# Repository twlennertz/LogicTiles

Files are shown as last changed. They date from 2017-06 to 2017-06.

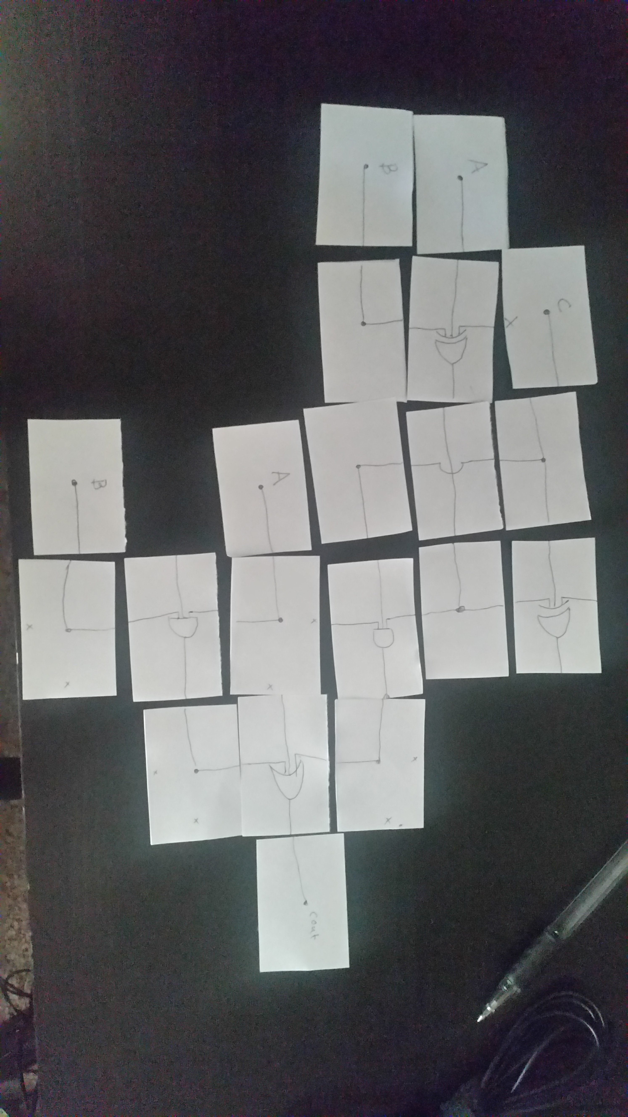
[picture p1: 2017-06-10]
non-code_project_files/Design Diagrams/rectangles.jpg

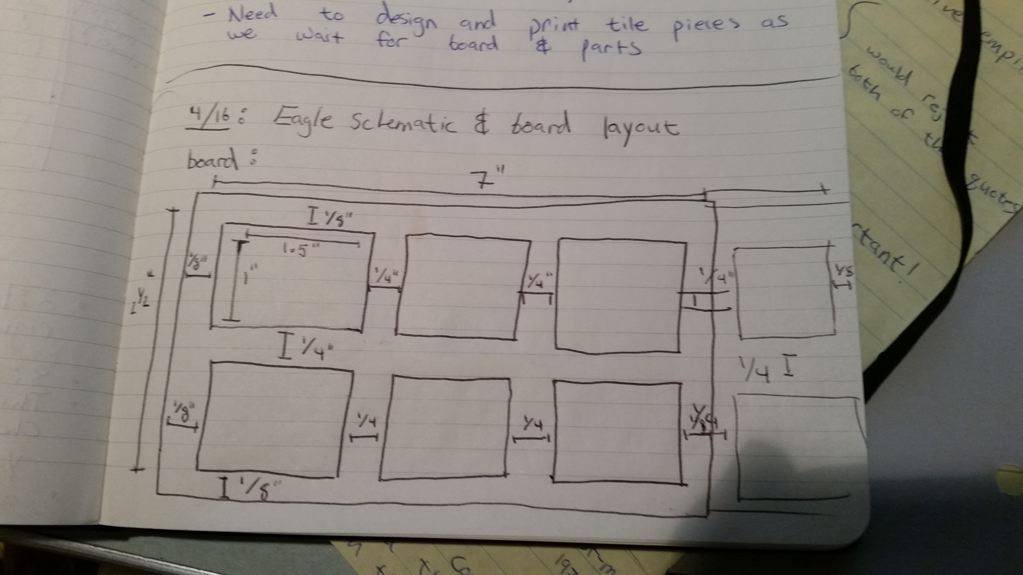
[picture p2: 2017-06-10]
non-code_project_files/Design Diagrams/Board_Dimensions.jpg

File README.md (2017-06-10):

<h2>Digital Logic Tile Board Project</h2>

Spring 2017 Senior Project

Cal Poly CPE Department

Authors: Tristan Lennertz & Andrew Wheeler

Implemented for the MSP430 Family

<h3>Please see Project Report for detailed information on this project</h3>

main: The main state machine loop, inits, terminal interface and commands, and ISRs

tiles: Pertains to addressing, selecting, reading, and determining the types of the tiles on the board

graph: Involves the creation and traversal of the graph that underlies and represents the digital circuit

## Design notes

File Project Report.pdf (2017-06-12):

# Logic Tiles

### A Senior Project

### presented to

### the Faculty of the Computer Engineering Department

### California Polytechnic State University, San Luis Obispo

### In Partial Fulfillment

### of the Requirements for the Degree

### Bachelor of Science, Computer Engineering

by

### Tristan Lennertz & Andrew Wheeler

### June 2017

©Tristan Lennertz, Andrew Wheeler

T

a

# ble

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
rvie

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
cisio

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
Tile

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
Tile

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
Tile

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
cisio

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
al Alg

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
Tile

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
r Im

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
# Introduction

## Overview

This project was originally conceived by Professor Andrew Danowitz as he considered the restructuring of the introductory digital design course at Cal Poly. As it stands now, students apply their knowledge of boolean algebra and combinatorial logic through the programming of a Field Programmable Gate Array (FPGA) using a Hardware Descriptive Language (HDL). While this is the industry standard for designing large, complex digital circuits, and is an fundamental skill to learn, there is a lack of actual circuit building in the process that can cause a disconnect from theory to application for students who have little-to-no experience with digital logic. Our project attempts to bridge that gap by providing a physical device with which students can manually develop their own digital circuits, forming them on a board as they place representative tiles onto it. They can then view in real time how their circuits are affected by certain inputs or restructuring of connections. This would be a useful supplement in the course that helps to emphasize the descriptive, and not procedural, nature of HDLs.

## Background / Design Decisions

To formulate the design of our project, we researched methods employed to teach programming to children and young adults. The closest thing we found to our project was a children's toy called Cubetto; Cubetto is a small robot that is controlled by a board that children place passive tiles onto in order to issue instructions. The concept of this board was very similar to the board we had envisioned, and so we did more research into Cubetto’s inception. This type of learning, called tangible learning, eventually led us to a thesis by Timothy McNerney of MIT in 1983, in which he proposed physical building blocks that were used to construct simple programs (his work would later lead to the development of the Lego Mindstorm series of educational toys) [2].

His application of the idea, however, was through the process of stacking many active units that would communicate via I

2C, which did not meet our desire to use passive tiles like Cubetto. McNerney’s work, lead us to an article by Andrew C Smith of the Meraka Institute who utilized passive elements on a board to manipulate a toy Robot [4]. From his research we discovered

that the passive elements contained a series of magnets embedded into them that would trigger specific reed switches on the board itself, giving each block a unique code that could be deciphered by a connected microcontroller.

We decided to use Smith’s technique but wanted to reduce the cost of the parts used. While Smith’s design was simple and used the presence and absence of a magnetic field to determine the encoding, required up to 9 magnets to be placed on each piece. Furthermore, each place for a block on the board needed 9 reed switches, so Smith’s prototype used a large and costly play field. Conversely, our project needed a multitude of different tile types and many small spaces on the board to place them. From this we decided to use Hall Effect sensors instead of reed switches, as a hall effect sensor can detect a magnetic presence in the same way as a reed switch, but it can also differentiate the magnetic strength and polarity [6]. This allowed us to use fewer magnets on our passive tiles and would instead vary the strength and polarity of the magnet.

We briefly considered RFID instead of magnets but decided to use magnets for a several reasons. First, though RFID tags have gone down considerably in cost in recent years, they would still be more expensive to implement. The least expensive RFID reader we found would cost about $10 and we would need at least one per tile space on the board. Compared to the hall-effect sensors (which cost <$1 each) the RFID reader’s cost per tile area would be close to (or even than) three times the cost of the number of hall-effect sensors we would need for the same tile area. Another advantage of magnets over RFID is that we can deduce orientation of our tile from magnets. RFID is unable to detect this, as it can only detect proximity, but we could gather the orientation from the polarity of the magnet.

## Project Goals

End Users

As stated in our overview, the main end users of our project are Electrical and Computer Engineering students. While they are assumed to have a certain degree of technical experience, we should expect that a majority of them have little or no skills related to digital logic and design. They should, however, have the knowledge to manipulate a simple terminal interface and light debugging skills.

Digital design professors would also use our system. Their main interaction with our system would be debugging student circuits. It is likely they would have prior training with the system and would be more knowledgeable in its operation than students.

Design Requirements

Seeing as our end users are students with little experience in digital design, we need to make sure that our device is robust and easy to use. Adding a new tile or gate to the circuit should be as easy as placing it on a corresponding place on the board and our system should quickly (within a second) detect that a new tile has been place and what the type the tile is. Students can then interact with the circuit using a companion terminal interface that is connected to the circuit board, allowing them to manipulate source values and read the signal value at various places on the circuit. Furthermore, we would like our system to be able to report to the student when they have incorrectly constructed the circuit and give them a hint as to where the problem lies. We do not want to directly tell them where the issue is as this is an education tool and the act of debugging the circuit is a part of the educational experience. We also decided that, because of the availability of physical space in classrooms and the variability of scale in digital design projects, we would like our design to not be permanently fixed to specific physical dimensions, but instead instead allow for modularly sized boards. Finally, because many of these boards would be needed in the classroom, our design should be inexpensive (relative to products of the same caliber such as FPGAs or children’s programming toys) to produce.

Engineering Requirements

From our design requirements, we can produce a series of engineering requirements that can be used to determine the course of our development process. Our requirements are:
1. Precisely control the detection of tiles and creation of digital logic circuit.
2. Within 1 second, detect the placement of a new tile and decode the strength and polarity of up to 3 magnets on said tile, determining its type and orientation.
3. Provide a terminal interface that takes in user input and communicated with the microcontroller using UART.
4. Keep costs of boards and parts ~$200 to 250.

# Hardware Design

Our system is composed of an array of hall-effect sensor clusters on printed circuit boards, mounted below the placement area for tiles on the board. Figure 1 shows our prototype tile board, with the PCBs mounted on a 3D-printed frame. A 3D-printed faceplate slots into the mount and makes it possible for the tiles to rest above each sensor cluster. Magnets on the underside of each tile carry information on the type of each tile, as well as what orientation it has been placed down in. Inputs can be applied using source tiles, whose values can be set via the terminal interface. Outputs can be read via probe tiles, which initiate a software interpretation of the tile circuit.

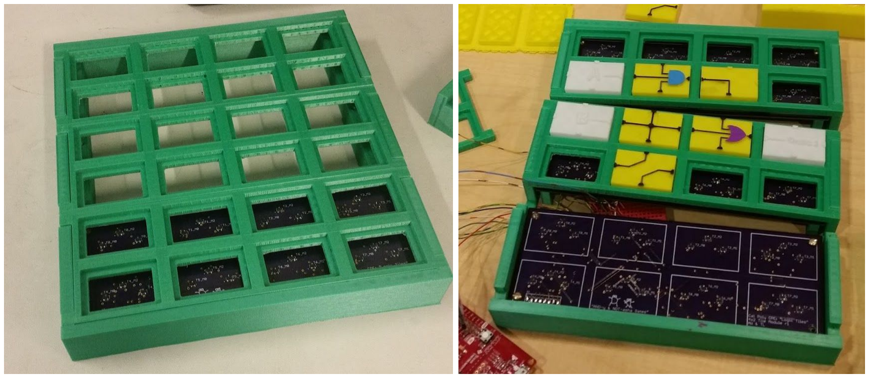
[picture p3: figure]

Figure 1: Tile board prototype with one PCB mounted (left), and sample tiles inserted with frame deconstructed (right)

## Tile Design

We explored two options when choosing the basic design of the tiles: A traditional rectangular tile, or a more novel triangular tile. We chose to consider rectangular tiles because of their familiarity with most people, while triangular tiles presented an opportunity to have more topologically diverse tile layouts without an excess number of possible orientations. Because of our needs for encoding and recognition of orientation, a minimum of 3 sensors per tile is required for either shape. With that important, resource-intensive consideration taken off the table, it came down to two main factors:

1. Compactness of the baseline circuit (a 1-bit full adder)
2. Intuitive use for a student
The first requirement minimizes the required board size in tiles, and thus the cost, while the second fulfills the primary objective of this project. Our strategy was to independently design a system of tiles for either shape and test them with first-time digital logic students. Figures 2 and 3 show example layouts with mockup paper tiles of either system.

Triangular Tiles

A unique challenge for the triangular tile system was the requirement for at least 3 possible inputs to gates whose operations accept it. Associating each tile side with an input or output left the gate tiles one input short. In order to overcome this, wires on a tile became one of two types: normal, or offset (dashed/dotted lines). Offset wires could be reached by wire tiles that converted normal wires to offsets. This meant that two signals could be bundled into one side of a tile, allowing for the a maximum of four possible inputs on each relevant gate. Additional considerations include the fact that tiles have 3 possible orientations when placed on the tile board. This makes an encoding scheme and its software interpretation potentially more complex.

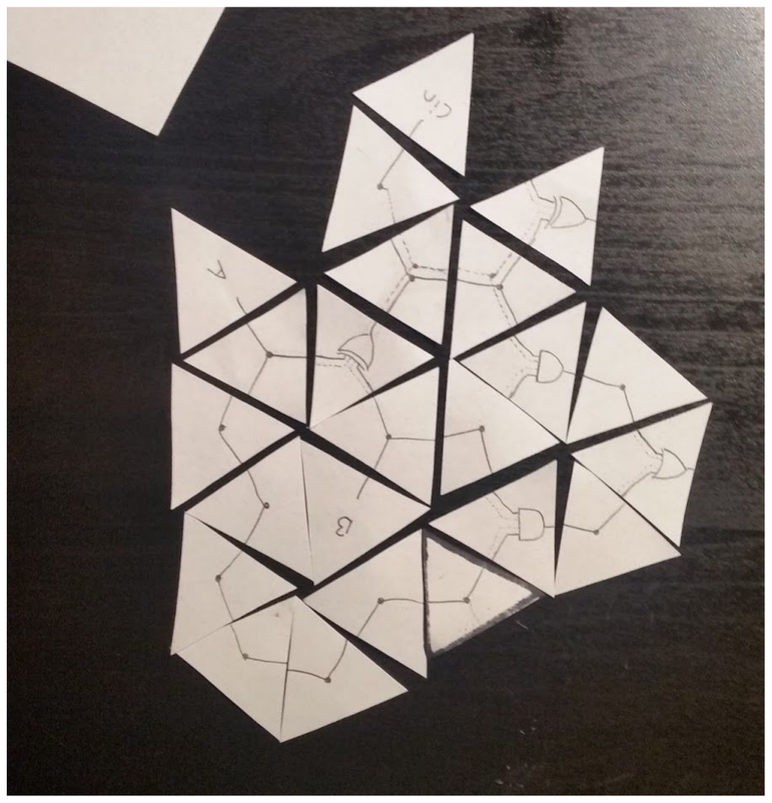
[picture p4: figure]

Figure 2: Paper Prototype of Triangular Tiles: 1-bit Full Adder

Rectangular Tiles

The development of the rectangular tiles were done with parallelograms in order to emphasize the need to limit the number of possible orientations to two. Four potential orientations, such as with square tiles, would require an additional sensor or inordinately complex encoding and interpretation to properly identify each potential direction a gate or wire could be facing.

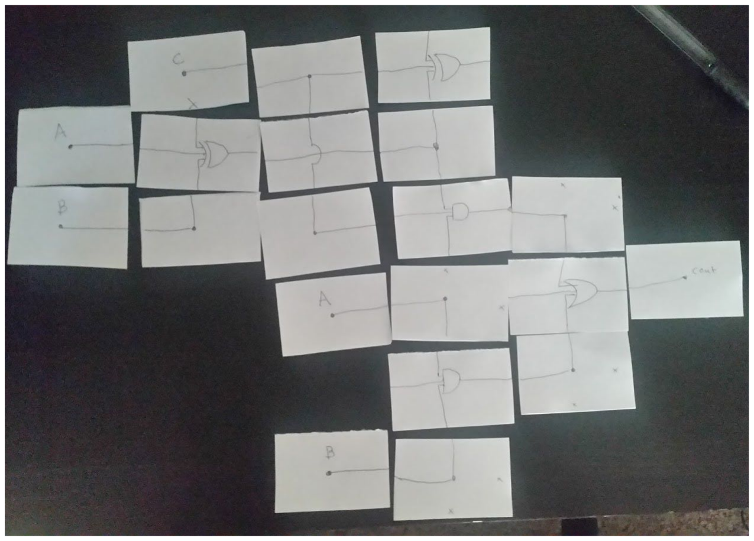
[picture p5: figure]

Figure 3: Paper Prototype of Rectangular Tiles: 1-bit Full Adder

Subject Testing and Decision

We tested both designs using paper tiles of each shape with students who were newly introduced to digital logic in CPE 133. We gave them a reference circuit to construct and minimal prompting on how the tiles were meant to be put together. After observing each student work, and asking them about the experience after, we drew several qualitative conclusions:

1. A rectangular layout if much more intuitive than triangular tiles to begin to pick up and begin building circuits with.

2. Triangular tiles could build the reference circuit much more compactly, but it was difficult for a student to take advantage of this without additional hints and tips along the way.
3. Without the proper tiles provided in the correct quantity, a circuit constructed with the rectangular tiles could become unmanageably large quite quickly in order to route the wires around each other correctly.

We ultimately decided that the ability for a student to pick up the tiles and begin building a circuit with almost no additional help from an instructor was more valuable to us than having as small of a tile board as possible, and have gone with the rectangular tiles. That said, the triangular tile system is fascinating and quite a fun novelty to build with. The bundling of wires between a normal and offset plane with the triangular tiles also proved to be a feature that could be very useful in the rectangular tiles. While we did not implement this feature with our rectangular tiles, it is something that could be added as an improvement in future iterations.

As observed in our subject tests, a danger with our the rectangular tiles in particular is not having enough of them, or of the right type. This is not an issue if a large number of tiles can be cheaply supplied, which is one of the requirements we have set out and designed our physical tiles to meet.

The tiles are all 1.5” x 1” rectangles, with the design of the component each one represents raised up off the tile face. There are four separate hole locations on the underside of the tile, as shown in an example tile bottom in Figure 4. The depth of each hole, as well as the polarity of the inserted magnet, determines the encoding value. The holes on either side of the tile (labelled mag0 and mag1) are used to provide a number of different encoding values to be detected simultaneously with separate hall-effect sensors on the board and used in combination with each other as identifiers for the type of tile being read. These encoding values are described in Table 1.

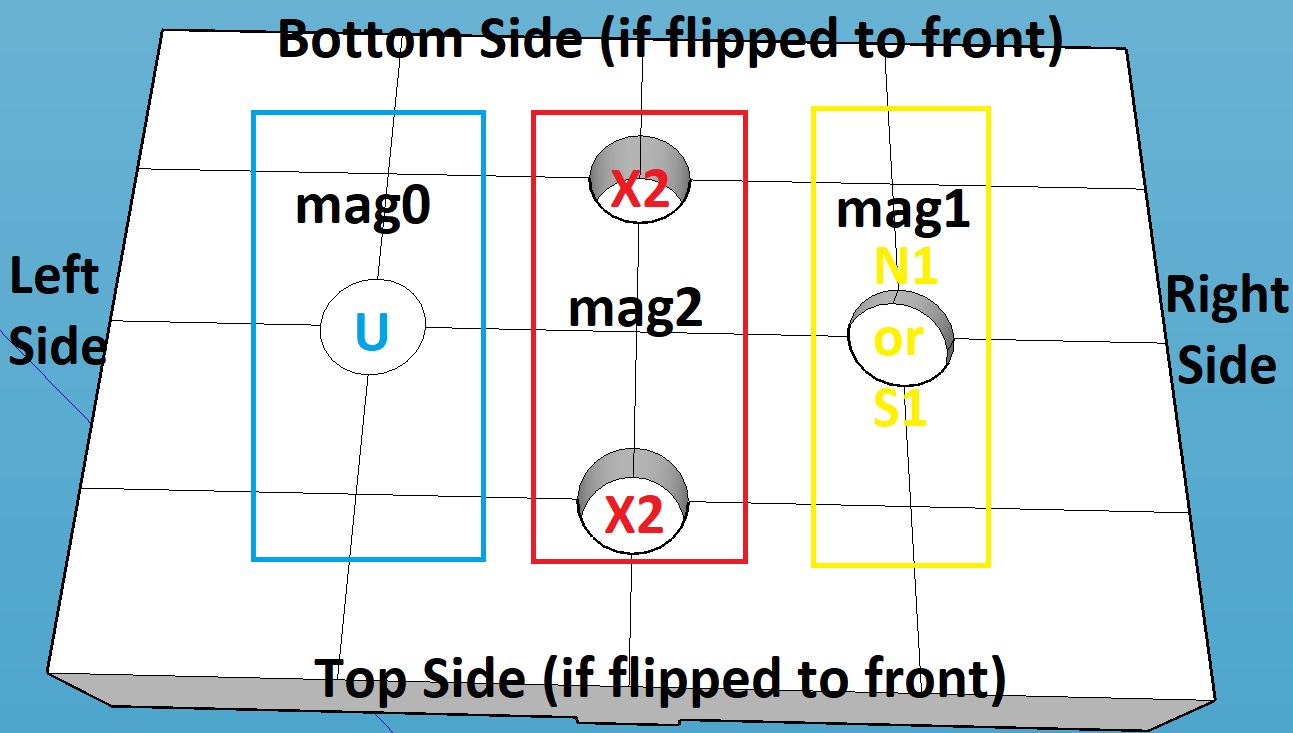
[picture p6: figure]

Figure 4: A tile bottom. Both mag2 holes are the same depth, despite perspective. Mag1 hole, if in mag2 place, would be X1

The central holes (labelled mag2) are used in conjunction with a single hall-effect sensor. This is the key to sensing the orientation. We have encoded the tiles such that the center (mag2) holes on any given tile always have the same magnitude. These are the same magnitudes as N1/S1 and N2/S2 described in Table 1, and are designated as X1 and X2 when referring to them as encoding values. While the same in magnitude, they have different polarities, with a northern polarity always being on the top central hole of the tiles, and a southern polarity always being on the bottom.
Table 1: Description of Tile Encoding Values
Encoding Value | Tile Hole Depth | Description
U | 0” | Simply the absence of a magnet, which is still a distinct range of values to be used as a valid encoding symbol. Is the quiescent voltage of the hall-effect sensor.
N1 | 0.045" | Just deep enough for the outward, north polarity face of the magnet to be flush with the bottom of the tile. This is the closer, “stronger” northern value, which will have the highest positive value range for the sensor.

Table 1 (cont.): Description of Tile Encoding Values
S1 | 0.045" | Same as N1, but with the south face flush with the bottom of the tile. Produces the lowest possible value range for the sensor. Note that while the magnets are 1mm in height, the hole depth is slightly larger to allow for 3D printing tolerances.
N2 | 0.125” | The deeper, “weaker” northern value (north side facing outward). This value range falls between U and N1.
S2 | 0.125” | The deeper, “weaker”southern value (north side facing outward). This value range falls between U and S1.
X1 | 0.045" | The larger magnitude for encoding the central magnets on a tile. Either N1 or S1.
X2 | 0.125" | The smaller magnitude for encoding the central magnets on a tile. Either N2 or S2.

Based on the orientation of the tile, we know whether to flip the read values from each side hall effect sensor (mag0 and mag1 in Figure 4) into the encoding fields for the tile in question, swapping them if the orientation is flipped. With the encoding fields of the tile sides properly assigned, and a magnitude of the center determined, the tile’s identity can be looked up, and the neighboring tile can be determined for each side.

We designed each tile so that they can be 3D printed with relative ease. Our final tile designs are shown in Table 2, with their identifying encoding values included. Note that the wire types labelled with numbers use hands on a clock, pointing to hours, as their guidelines. Although the clock naming scheme makes for unambiguous tile names, some of them were created so that their describing names are most apparent in the flipped orientation. For example, a WIRE_9_12 describes a wire running from the 12 o’clock position to the 9 o’clock position. However, this describes flipped orientation best, with the right-side-up orientation more apparently showing a wire running from 6 o’clock to 3 o’clock. These are the same tile, however, and no WIRE_6_3 exists.

Additionally, while AND, OR, and XOR gates can take up to three inputs, two is still the minimum number required to be valid. Multiple source / probes tiles are also excluded from this table, as their designs are extremely similar. Their codes also follow incrementally from the first examples provided here, and can be referenced/modified in the provided code for this project if needed.

Table 2: Final Tile Designs and Encoding Values

Name | Design | mag0 | mag2 | mag1

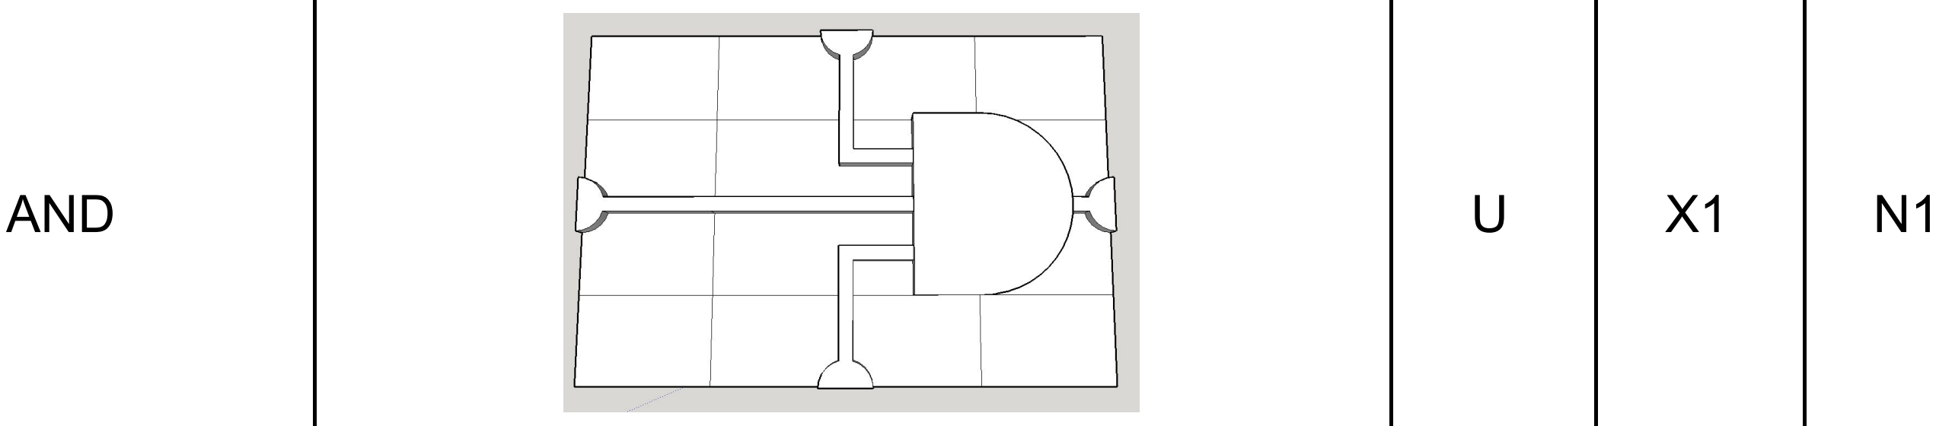
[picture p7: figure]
AND
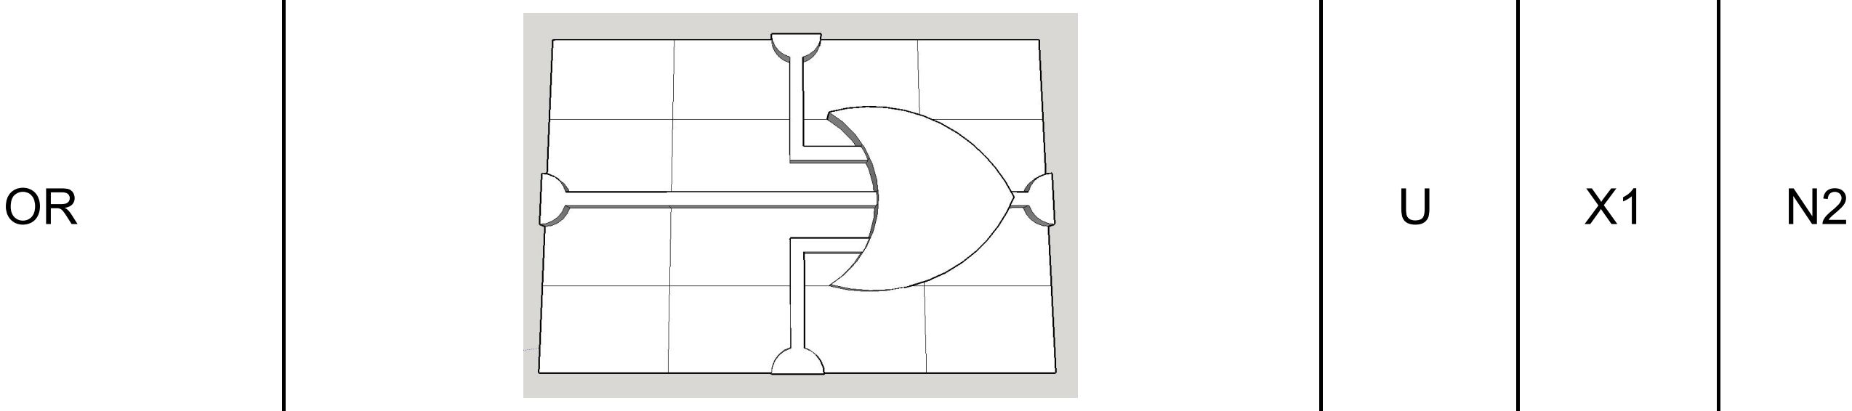
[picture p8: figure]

Table 2 (cont.): Final Tile Designs and Encoding Values

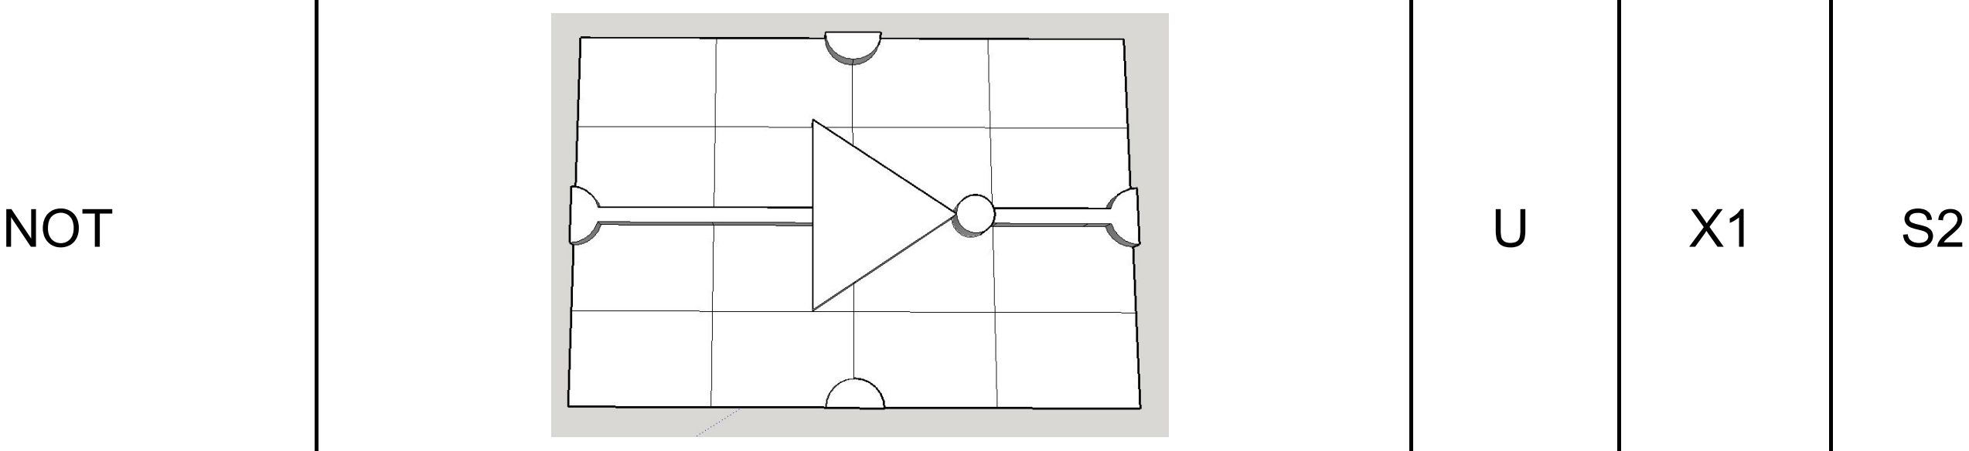
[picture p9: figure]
NOT
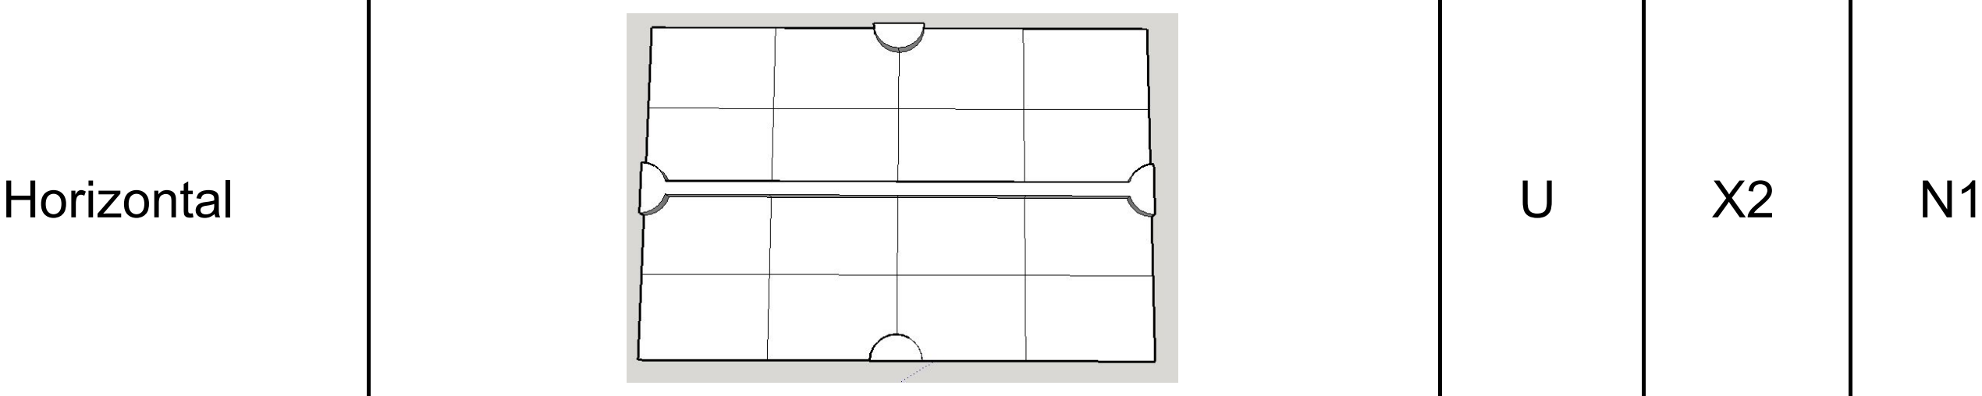
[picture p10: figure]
Horizontal
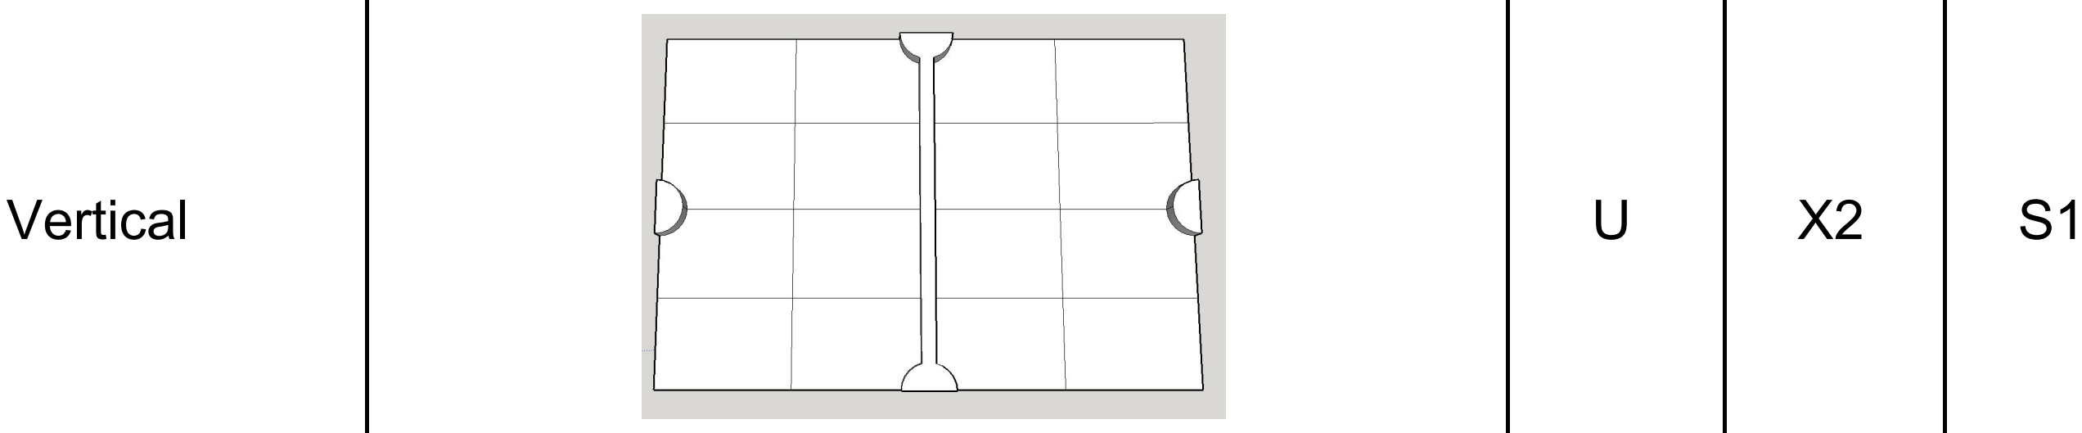
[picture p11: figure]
Vertical
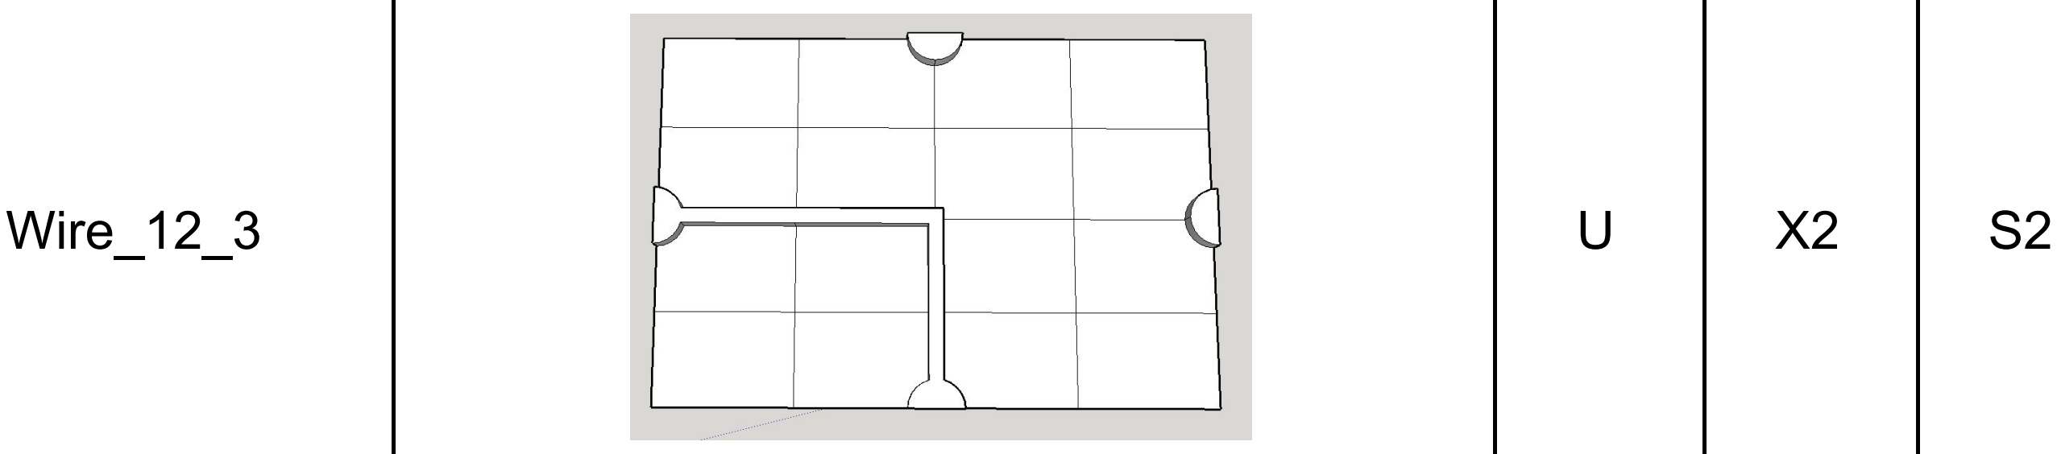
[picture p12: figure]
Wire_12_3

Table 2 (cont.): Final Tile Designs and Encoding Values

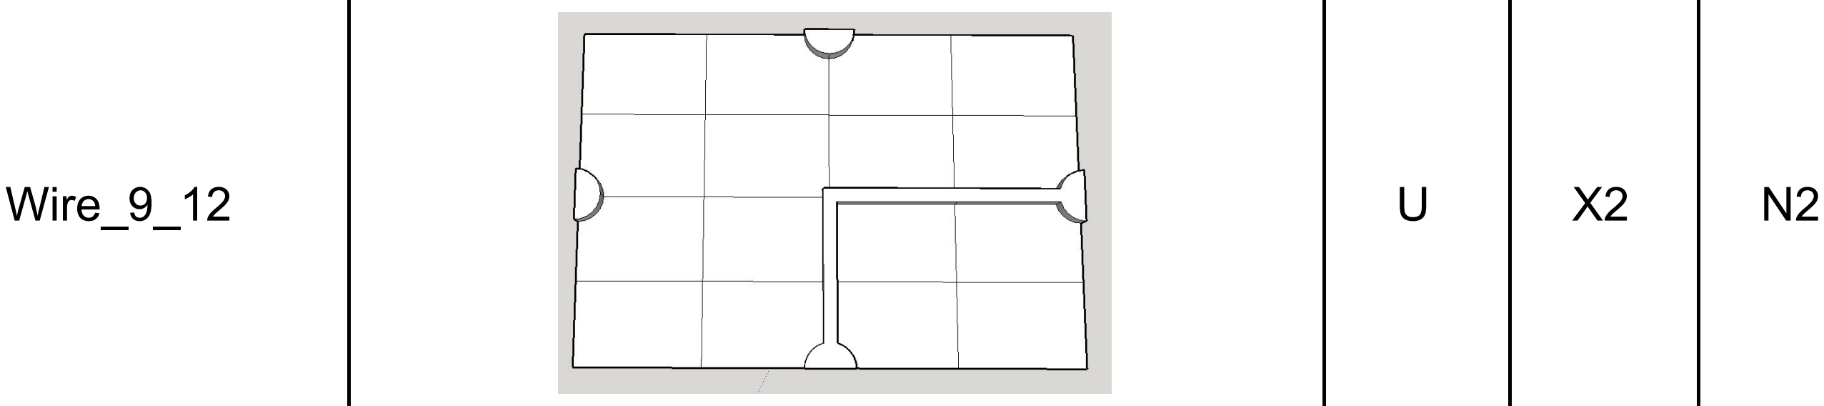
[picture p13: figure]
Wire_9_12
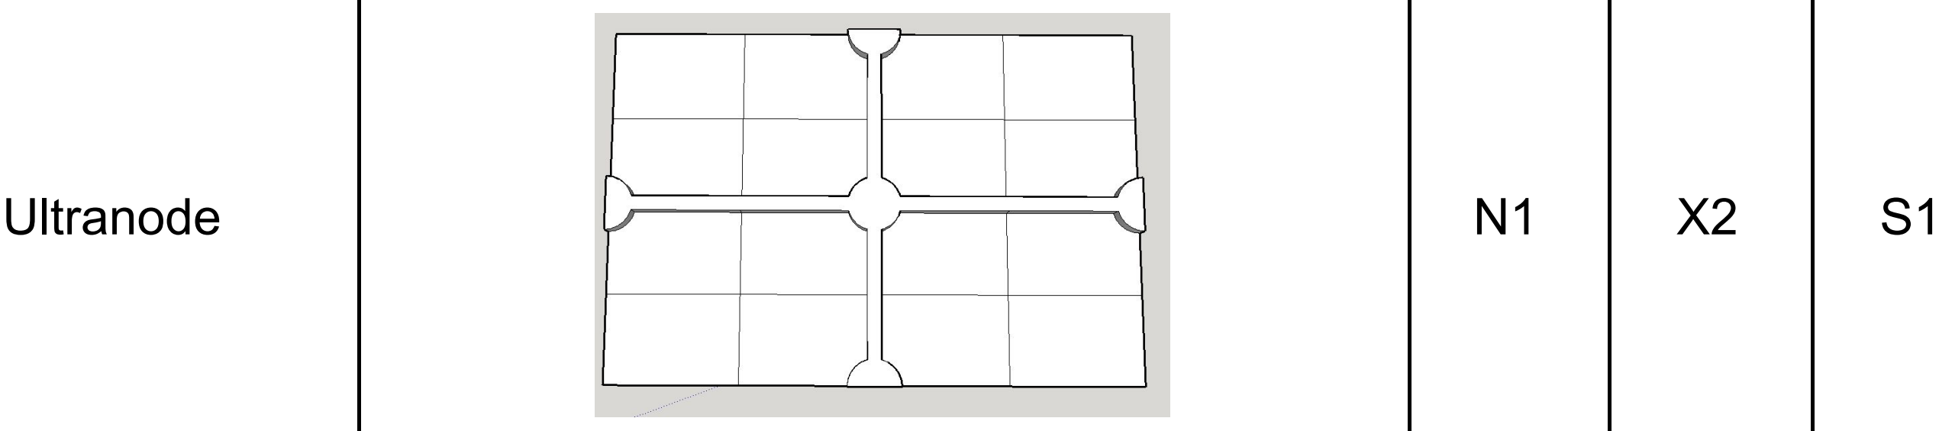
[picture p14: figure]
Ultranode
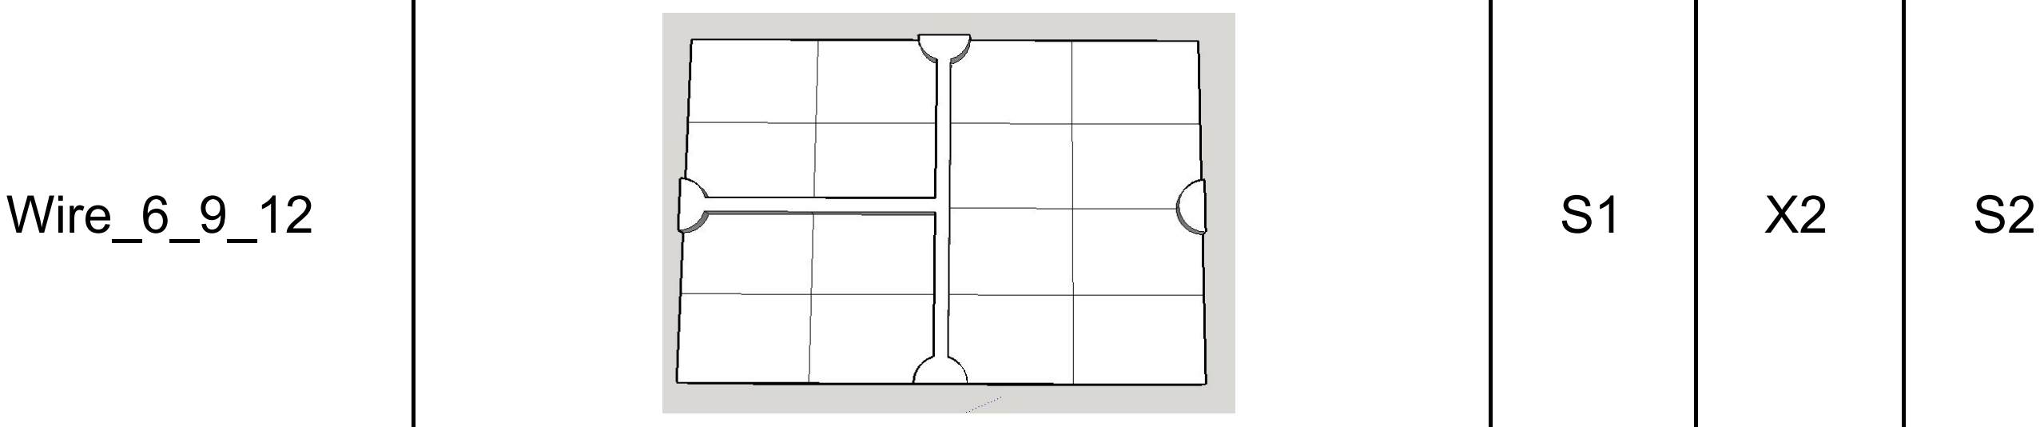
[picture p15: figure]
Wire_6_9_12
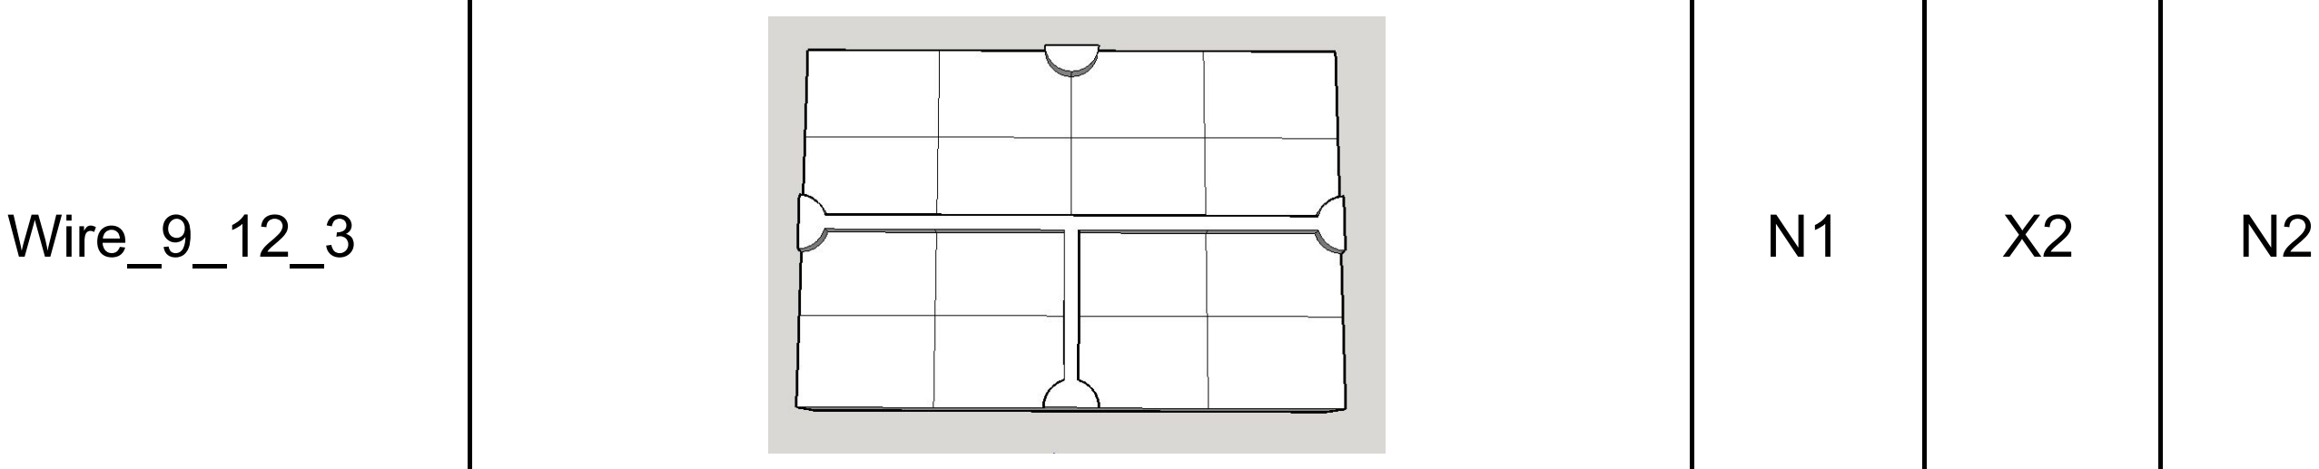
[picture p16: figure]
Wire_9_12_3
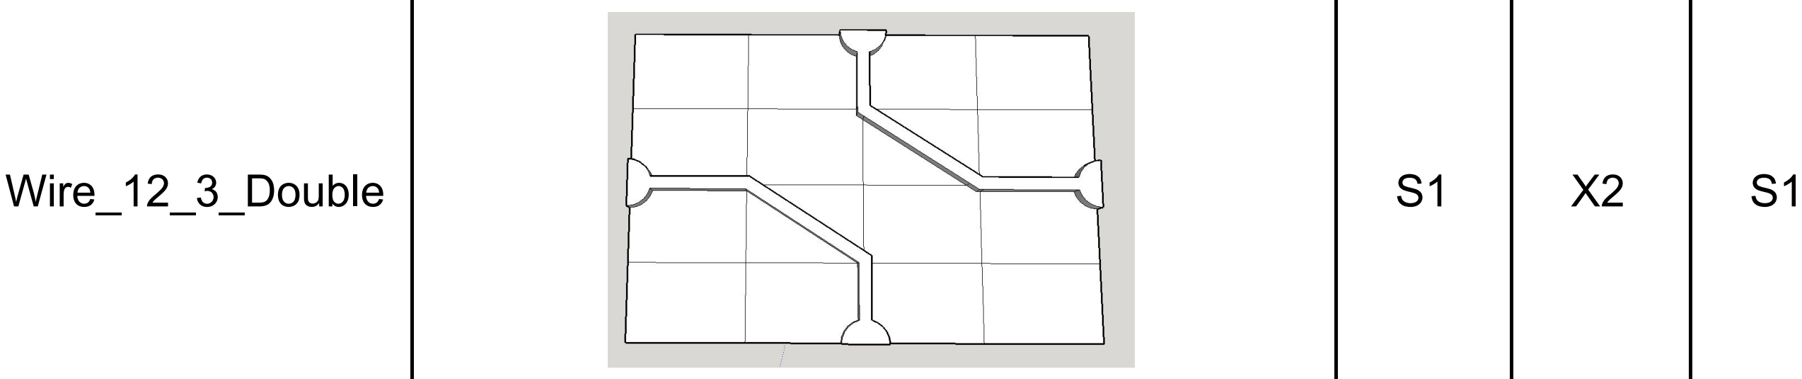
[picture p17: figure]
Wire_12_3_Double

Table 2 (cont.): Final Tile Designs and Encoding Values

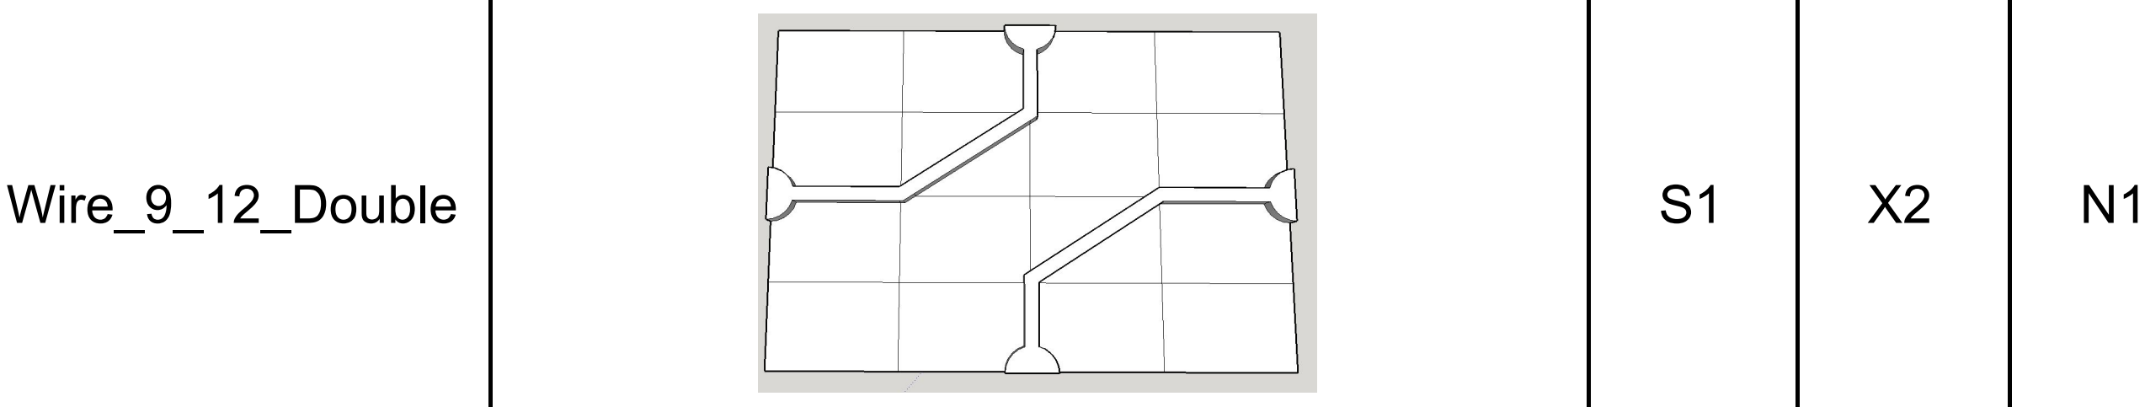
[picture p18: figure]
Wire_9_12_Double
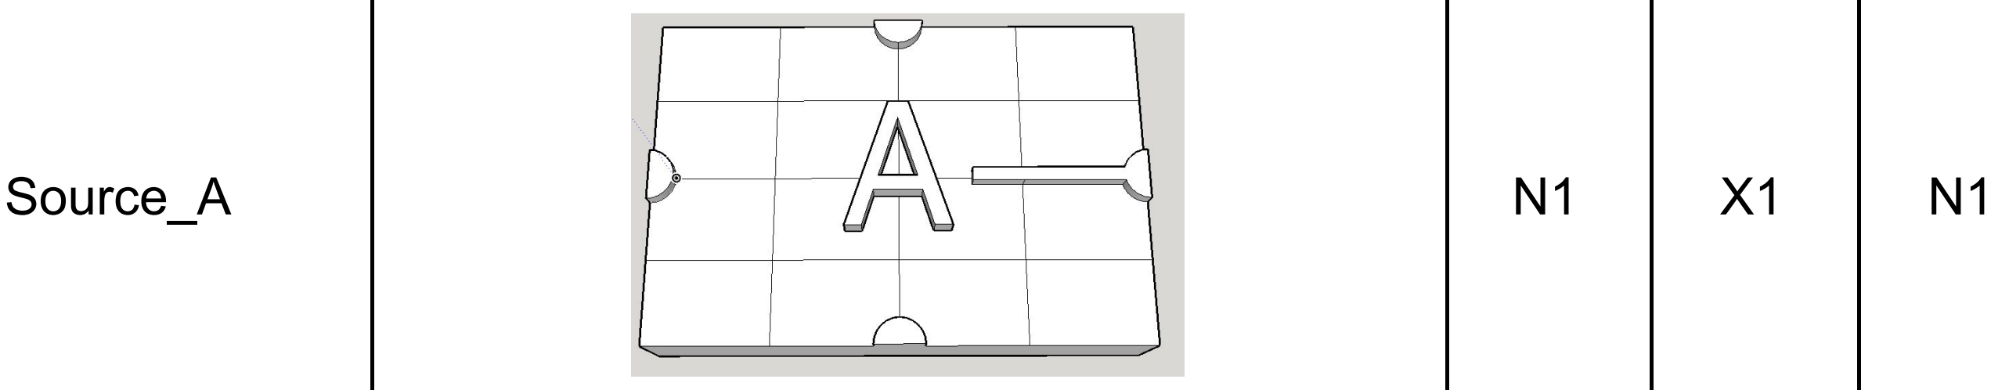
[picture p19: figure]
Source_A
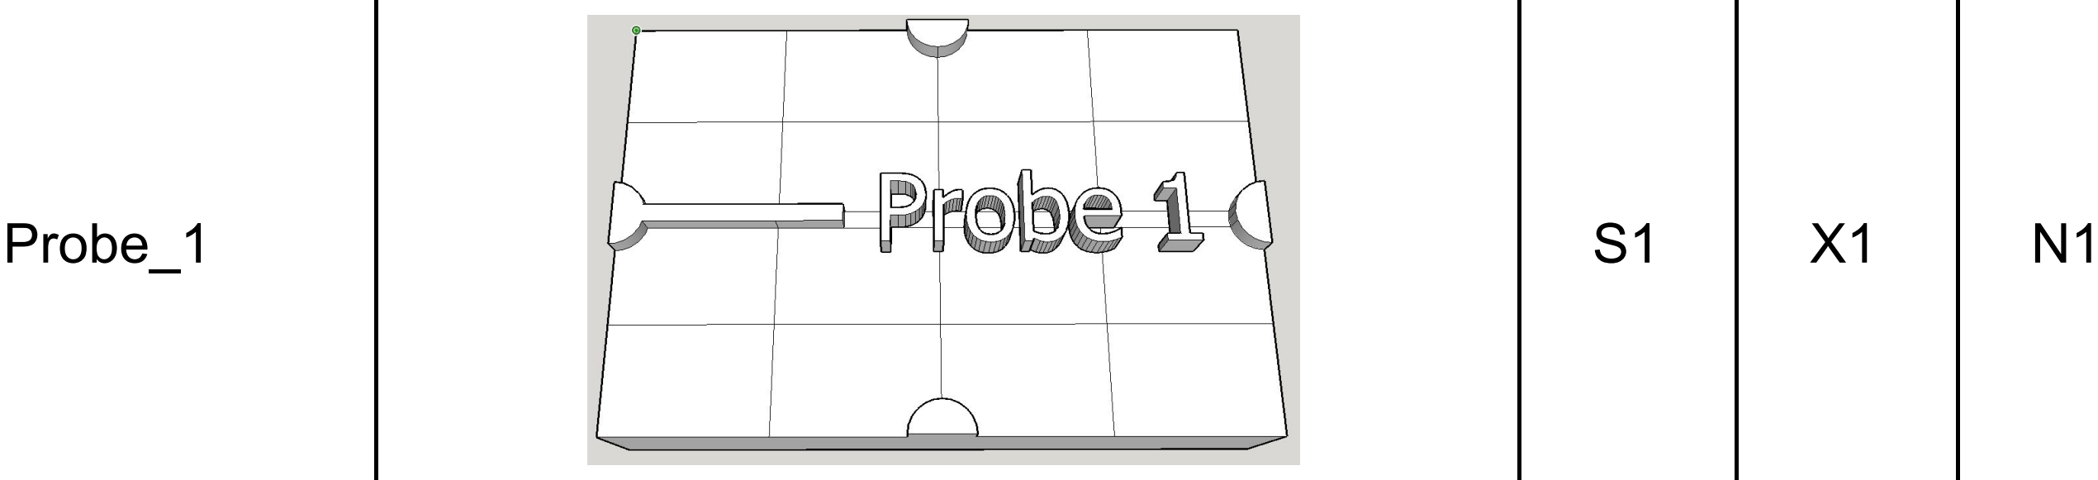
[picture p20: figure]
Probe_1

These tiles are available in the project files as Sketchup projects to be modified, or .stl files to be 3D printed.

## Board / Module Design

Our aim for the tile board was for it to have clusters of the three sensors below each area where a tile could be placed. We opted to mount these clusters straight onto a printed circuit board in order to obtain the precise placements needed for consistent measurements across all tiles. Instead of designing a single, monolithic PCB to sense all of the tiles in the end product, we opted for a more modular design in which each PCB is a rectangular 4 x 2 tile board. These modules could then be grouped together in order to form larger boards as needed. There were several benefits to this:
1. Less initial investment in the design and development of a prototype board.

2. More scalability in the size of the final board. The intended final size for a board to make the baseline 1-bit full adder circuit is a 2 module x 3 module (8 tile x 6 tile) tile board. That said, the use of modular components mean there is no practical cap on what the size could be.
3. Development and testing done on a single module of 8 tiles is less cumbersome and helps avoid confusion in debugging.
4. A dimension of 4 tiles x 2 tiles works nicely in terms of software manipulation. Besides the dimensions being a base of 2 (allowing for shift and masking optimizations), the number of actual tiles, 8 (a byte), makes room for even more potential software tricks and numberwangs .

1
These modules, besides providing the backbone of the board and precise sensor placements, also serve to multiplex the outputs of each sensor together in a way that is easily accessible to the tile board’s microcontroller. It is designed so that each module has only one analog output pin, and any magnet on the board can be selected for that output with the 5 selection pins, described in Table 3.
Table 3: Module Pin Descriptions

Pin(s)

TILE_SEL0 - TILE_SEL2 | Selects which magnet cluster of the 8 on a module will be multiplexed to the output. SEL0 is the LSB, with 0x0 corresponding to tile 0 on the module, and 0x7 corresponding to tile 7.
MAG_SEL0 - MAG_SEL1 | Selects which magnet out of any of the clusters will be MUXed as the output. MAG_SEL0 is the LSB. NOTE: In our selected 3:1 MUX, 0x0 is a high-impedance output for the chip. 0x1 corresponds to mag0, 0x2 to mag1, and 0x3 to mag2.

1 https://www.youtube.com/watch?v=qjOZtWZ56lc

Table 3 (cont.): Module Pin Descriptions
A_OUT | The analog output of the module. This is the only signal that cannot be shared with the other modules. With our chosen sensors, should range between 0-2V, or high-impedance (if 0x0 selected on 3:1 MUX)
VCC | Input voltage can be 3.3-5V, as it does not affect the sensor output. 3.3V recommended, as that is the VCC of our selected microcontroller and uses less power.

Essentially, there are two stages of multiplexing on the board. First, all magnet sensors of the same number (e.g. all mag0, all mag1, or all mag2) are multiplexed together on an 8:1 MUX. There are three of these MUXes – one for each magnet number – that take one magnet from each of the 8 tile clusters on the board. The three outputs of these MUXes are then fed into a 3:1 MUX, the output of which is the output of the module. When integrating multiple modules into a single board, for any given select pin on a module, that same pin on any other module will share the same signal line. That is, the number of GPIO pins on the microcontroller allocated to selecting tile magnets will always remain at 5.

The microcontroller will determine what selection pin values are appropriate for the given tile/magnet on the board it is trying to access, and apply those signals to all of the modules at once. In determining what select pins to use, it will also determine which module a tile is on, and will be able to read that desired module’s output. The separate modules’ outputs can either be multiplexed together, or simply attached to different ADC pins on the microcontroller. We have opted to use the latter approach, but a good followup on this project would be to design an auxiliary board that serves to interconnect any given number of modules together in a way that is easy to assemble and access those modules with.

Figures 5 and 6 are from the module schematic, and show one of the sensor clusters and part of the MUXing scheme, respectively. Standard 0.1μF decoupling capacitors have been added for stability. A full image of the schematic is available in pdf form with the project files, as is the actual board layout. Eagle files are included for both as well.

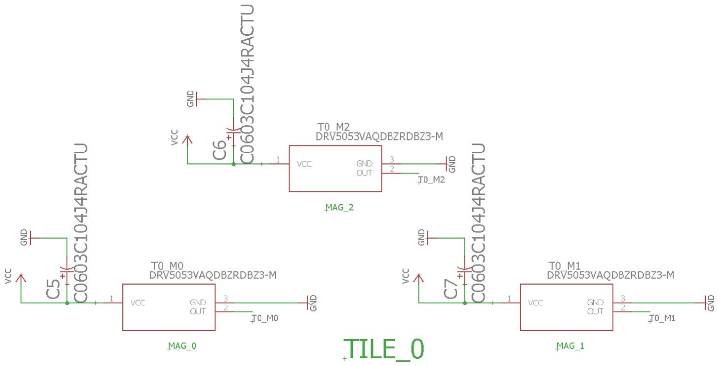
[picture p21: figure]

Figure 5: Sensor Cluster Schematic

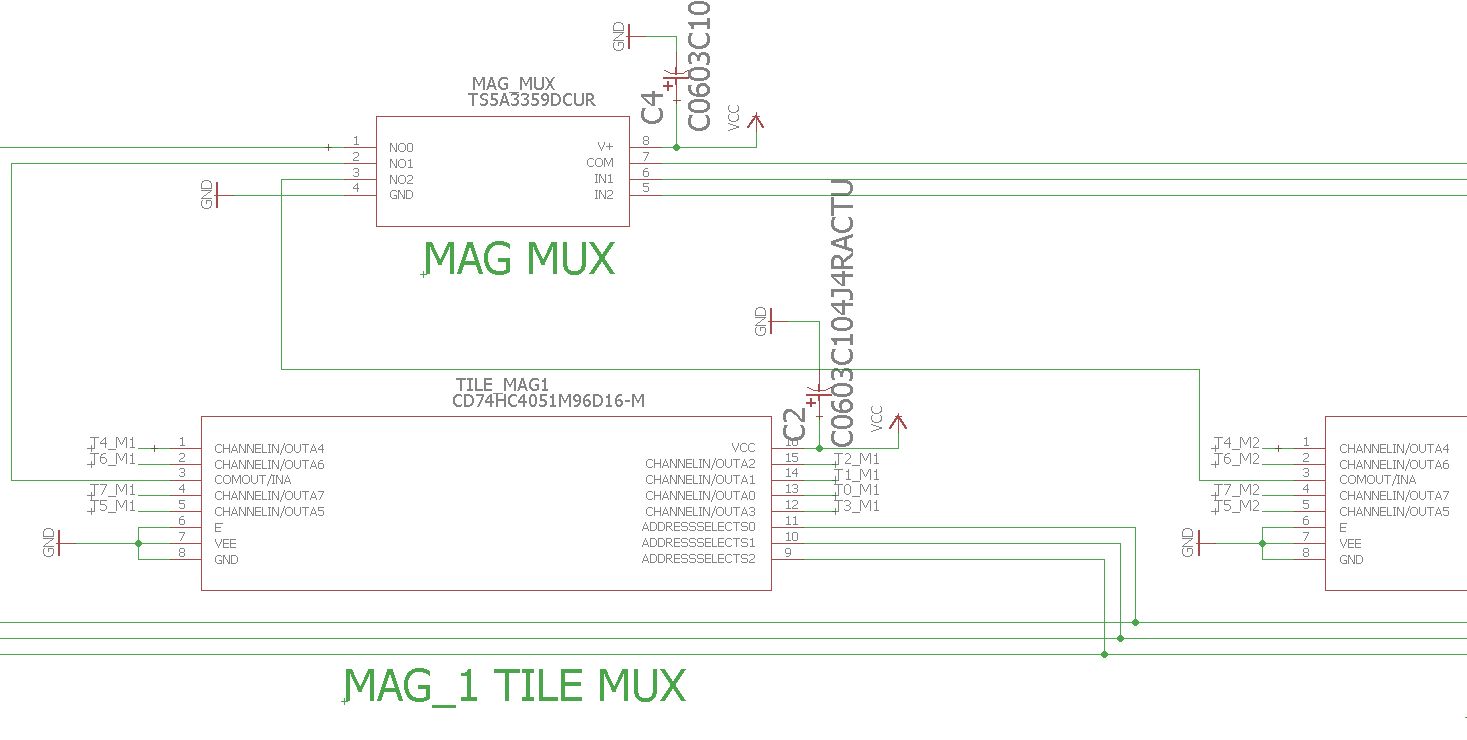
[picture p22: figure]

Figure 6: Partial Schematic of Module Multiplexing Scheme

The selected components’ part numbers, maximum current draws (if applicable), and quantities per module are listed in Table 4 below .

2

Table 4: Module Component Descriptions

Component | Part Number | Quantity | Max Current Draw (mA)
8:1 MUX | CD74HC4051M96 | 3 | 0.08
3:1 MUX | TS5A3359DCUR | 1 | 3.6
Hall-Effect Sensor | DRV5053VAQDBZR | 24 | N/A (negligible)
0.1 μF Capacitor | C0603C104J4RACTU | 28 | N/A

The maximum current draw is about 90 mA per module, although in practice we have measured a typical value of 60-70 mA per module. At VCC = 3.3V, each module consumes a maximum power of about 0.3W, although again we have found it to be about 0.2 - 0.25W per module.

2 Maximum values determined from manufacturer's datasheet for each part.

Figures 7 and 8 show the final fabricated and assembled module board .

3

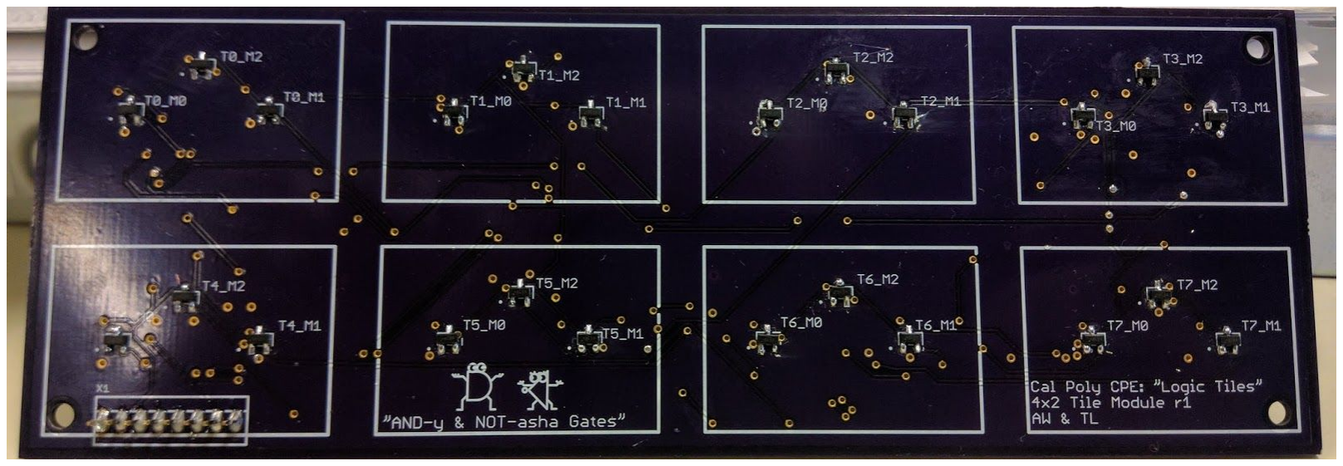
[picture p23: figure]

Figure 7: Physical Module PCB Front

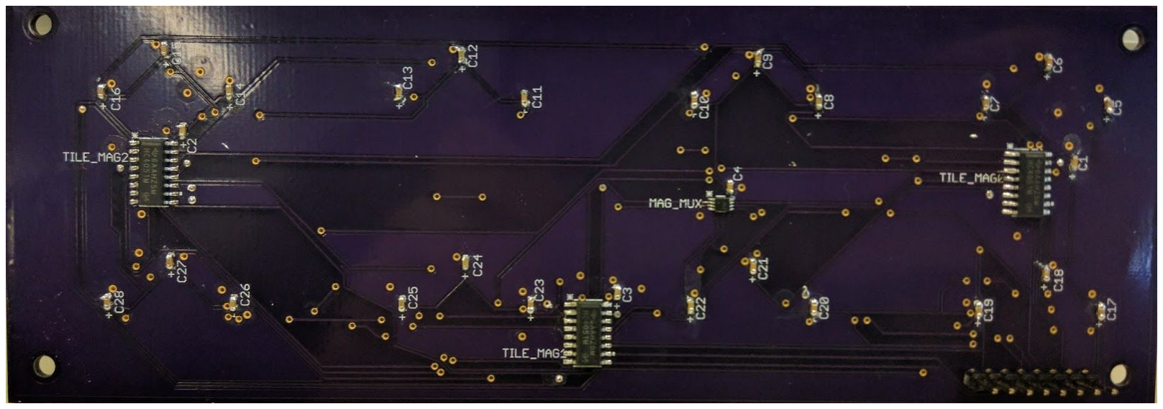
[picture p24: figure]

Figure 8: Physical Module PCB Back

We have additionally designed and created mounts for the modules that can be fit together to form complete tile boards of multiple modules. These mounts are available in the project files as Sketchup projects to be modified, or .stl files to be 3D printed.

# Software Design

Our firmware runs on an MSP430FR5994 microcontroller and performs several functions. It needs to be able to read magnet values and construct a simulated version of the physical

3 AND-y and NOT-asha Gates are claimed as intellectual property by the authors, but may be freely reproduced non-commercially, or otherwise with express written permission.

circuit, as well as interpret commands issued from a connected terminal interface. Our software consists of a state machine that dictates program flow, updating data structures that store information about tiles on the board and dispatching to terminal commands as necessary. In order to read values at points in the circuit it performs a recursive graph traversal algorithm we have implemented for the graph that serves as our digital representation of the tile-based circuit.

## Data Structures

There are a few main data structures that store the data related to our system. One of these structures is the array of all the tile spaces on the board. This contains the current magnet value of each tile, the type of tile that the magnets resolves to, the orientation of the tile, and the circuit graph nodes connected to each side of the tile. These are stored as a TileState struct as seen below. These TileStates are stored as an array in which the tile number of the board is its index into the array.

typedef struct TileState { magcode mag0;
magcode mag1;
magcode mag2;
tileType type; | // determined by the encoding of mag0-mag2
int orientation; | // 1 is normal orientation, -1 is flipped (upside-down)
struct Node *leftNode; | // not all will be used for each tile type
struct Node *rightNode;
struct Node *topNode;
struct Node *bottomNode;
} TileState;

Another important data structure is the Node. These represent the connections between tiles and will be the primary method by which the logic circuit will be constructed and analyzed. These nodes contain information on which tiles they connect, whether it’s been visited before (to avoid graph traversal loops), and the logical value at that node during traversal. There is also a Node pointer field for use in a free list of Nodes, as all possible Nodes are preallocated in order to avoid dynamic allocation.

typedef struct Node {
/* Two tiles the node is bridging */ TileState *tile1;
TileState *tile2;

uint8_t visited; | //for recursive graph traversal
digiVal value; | //also for graph traversal
struct Node *next; | //for use in the free list
} Node;

## State Machine

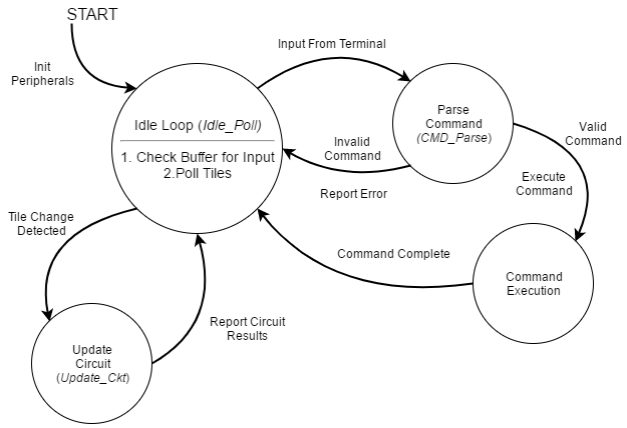
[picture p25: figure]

Figure 9: Software State Diagram

As diagramed above, the main control of our firmware is dictated by a finite state machine that’s implemented in our main function. The state machine contains three main states: Idle_Poll, CMD_Parse, and Update_Ckt. The following describe the functions of all the states:

Idle_Poll
Idle_Poll is the default state that handles idle operation of our system and checks for changes in the current state of the board. The first thing it checks is the data input flag that is set if there is UART data available for reading. If there is data then Idle_Poll will return the state CMD_Parse, otherwise it will begin polling the tiles for changes. The act of polling the tiles involves reading the M2 magnet of each tile on the board and comparing it to the stored value. If it differs then a the entire tile is read (all three magnets) and Idle_Poll will return the state Update_Ckt.

CMD_Parse
As the name suggests, CMD_Parse parses any commands that come in through the UART connection. If the string matches a known command, then that command is executed, otherwise it ignores it. This function will always return to Idle_Poll.

Update_Ckt
Update_Ckt is the state that handles the reevaluation of the digital circuit the user created. If a probe is present (one needs to be present to evaluate the circuit) it will begin the circuit traversal algorithm described below.

## Circuit Traversal Algorithm

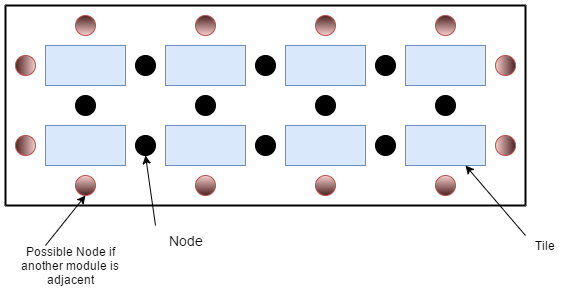
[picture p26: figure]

Figure 10: Graph Node Layout in Relation to Physical Tiles

The algorithm is a recursive graph traversal, with source tiles and dead ends serving as base cases. Each traversal starts with a call on whatever probe tile is currently being considered, as well as its left node (where the probe connects with other parts of the graph). Each call of the function locates which side of the parameter tile the parameter node belongs to. What next happens depends on the type of the tile and which side of the tile that node happens to be. In general, however, it will make further recursive calls on the other relevant nodes of the parameter tile, and then perform an operation on the return values based what type of tile it is. The result of this operation is then returned. Below is high-level pseudocode of the algorithm:

digitalValue : {ONE, ZERO, INDETERMINATE}

digitalValue getNodeValue(Node n, Tile t) { digitalValue returnValue = INDETERMINATE;

if (n != NULL && t != NULL) {
/* determine the tile type of t */
/* determine which side node of t is n */

digitalValue temp1, temp2, temp3;
Node sibling1, sibling2, sibling3;
Tile neighbor1, neighbor2, neighbor3;

if (n is not visited) {
/* visit n */

/* Note: not every node of t will be recursed like this. The type of the tile and * side of the node will determine which siblings/neighbors to make a call on */ sibling1-3 = nodes of t that aren't n
neighbor1-3 = the tile that each sibling node connects t with (NULL if none)

temp1 = getNodeValue(sibling1, neighbor1);
temp2 = getNodeValue(sibling2, neighbor2);
temp3 = getNodeValue(sibling3, neighbor3);

n->value = returnValue = /* Perform operation on temp1-3 based on type of t */ }
else
returnValue = n->value;
}

Return returnValue;
}

The return values correspond to digital logic high (1), low (0), and indeterminate. Source tiles will not end up recursing, but immediately return their currently set value. Dead ends are the same, but with an indeterminate value. The operations performed by each tile are as follows:
1. Gates check that there is at least two (for AND, OR, XOR) or one (NOT) non-indeterminate values as operands. If there are not enough valid values, the operation returns indeterminate. Otherwise it performs the operation across all valid inputs and returns the result.

2. Wires check that there is one (and only one) value that is non-indeterminate. If there aren’t any valid values, it returns indeterminate. If there is more than one valid value, it signifies bus contention, and returns indeterminate

# Implementation / Results

## Testing

In our system there are two functions that need to be independently tested: the correct detection of tile types and the correct graph creation and traversal of the desired digital circuit.

### Tile Detection

The testing procedure to determine the correct interpretation of tiles is relatively straightforward; we simply placed each encoded tile on the board and used our terminal interface to report what type of tile was detected at that position. If the tile was correctly typed, then we would test to determine if our system could detect if the tile was flipped. If our system could not correctly detect the correct tile type, then we could have the raw ADC values output to the terminal. This would allow us to determine if it was the tile itself that was producing a bad reading of the magnet or if our software was incorrectly typing the tile based on correct read values. This also allowed us to build ADC read ranges for each of the given encoding values.

### Circuit Creation

We must make sure that detected tiles are integrated properly into the underlying graph data structure. Testing involves reading the connecting nodes of each tile to make sure the graph is well-formed, and then running the traversal algorithm from the probe in order to make sure it recovers the correct result.

To begin, we would use a logical NOT with one input signal and a probe. After this test succeeds, we would then try the other gates (AND, OR, XOR) with two inputs. For each gate we would try all combinations of inputs, verifying that the gate’s truth table can be implemented. When all gates work properly we would tring multiple gates together and test.

## Results

As of now, we can accurately detect and discern when a tile is placed on the board with reliable accurately. We initially had numerous issues with the ranges we were using to detect certain magnetic field strengths. This is because our initial distance between the module sensors and tiles were too far, causing the magnetic field (and thus ADC read values) to be fairly weak, and the resulting ranges for each encoding value to overlap. Ensuring proper ranges of the encoding values is the most challenging aspect in making this project work. We did not have the time to recreate a mount for the modules that would bring it close enough to the tiles, but we were able to mitigate overlaps in two ways:
1. Decreasing the depth of the X2 holes in order to move their ranges away from the U value.
2. Adding a second magnet onto the X1 magnets in order to distance their ranges from the X2 ranges.
It’s important to note that these are temporary solutions done in order to produce a proof of concept that can be furthered with later iterations of this project. Decreasing the module sensor distance from the tiles is the only permanent solution.

In addition, the graph creation and traversal algorithms all work as intended. The only hiccup in testing them was unreliable tile detection, as described above. It should be noted that we only ended up fabricating and connecting three modules, as opposed to our vision of six. This is because of the expense and time in fabricating additional boards. This project was not sponsored, and so we were constrained with standard project funding. That said, integration of three additional modules should only involve changing values in the source code, as well as making the appropriate physical connections.

## Further Implementation / Next Steps

We believe that we have made our logic circuit board a solid foundation for further implementation. To begin, there are a number of hardware alterations that can be made to improve the reliability of the system. They are outlined in Table 5.

We believe that a good feature to implement would be to transcribe the circuit into HDL that can then be uploaded to an FPGA. Writing HDL and viewing it on an FPGA board is one of our main reasons for this project and having it in turn create HDL would have this project come full circle. Students could also use this computer generated HDL code to corroborate their own work.

In addition, a large design component to be explored is an auxiliary board that serves to connect multiple boards. Forming reliable connections between the microcontroller and each module, including good grounding and Vcc, was inordinately difficult with breadboard and crimping, and this would address that issue.

Another important feature that would be good to implement would be sequential logic. As of now, our system only works with combinatorial logic. While this is fine, we believe that this project will more useful as an educational aid if it can implement sequential logic gates such as latches and flip-flops. Sequential circuits are typically more difficult topics for students to master and the visual representation provided by our project would be an effective aid.

Table 5: Important Alterations to Final Design

1. Module Mount | Fixes to the module mount to close the distance between sensors and tiles. This includes appropriate depth changes to tile magnet holes in order to create the most distinct ranges.
2. Alternative Sensors | Our sensors have a voltage range of 0-2V, regardless of Vcc. With the above fixes to tile and sensor distances, this should be plenty of range for the encoding values. However, if more encoding values or wider ranges are desired, using a hall-effect sensor that bases its ranges on 0-Vcc Volts would allow for it more easily. No changes should be needed to PCB layout either, as the footprint and package used is fairly common for these types of sensors.
3. Support Structures | Support structures on the underside of the tile faceplates in order to keep them from bowing inward.

# Conclusion

In closing, we have successfully completed our project and have developed a system that has great potential as a learning aid. We have demonstrated how a system of tiles may be designed so that they are encoded with varying magnetic field strengths, and interpreted with a cluster of hall-effect sensors. Furthermore, we have shown that they may be encoded and interpreted in such a way to allow their orientation to be taken into account. The data structures and algorithm we implemented also successfully construct and interpret the digital circuit the user creates on the board. The terminal interface we’ve created provides a fairly intuitive method to assign source values and discern output values. We were even able to keep our system relatively cost effective; in the end our system cost around $220 to produce.

There were several difficulties that presented themselves throughout the project, especially including the later stages. In any system like this, it is imperative to ensure that the ranges of magnetic field strength for each encoding value are all wide enough, and non-overlapping with each other. We struggled with this through the end, and an important point of focus for any continuation on this project would be the value ranges. We were also unable to fully assemble a 2 x 3 module board as we originally envisioned. Both time and minimal funding prevented us from doing so, but we hope that the groundwork laid out is sufficient enough to encourage future work to make it a reality.

# Works Cited

[1] T. McNerney, "From turtle to Tangible Programming Bricks: explorations in physical language design", Personal And Ubiquitous Computing, vol. 8, p. 5, 2004.
[2] T. McNerney, "Tangible Programming Bricks: An approach to making programming accessible to everyone", Master of Science, Massachusetts Institute of Technology, 1999.
[3] A. Smith, "Tangible Cubes as Programming Objects", ICAT'06, 2006.
[4] A. Smith, "Using Magnets in Physical Blocks That Behave As Programming Objects", Meraka Institute.
[5] Texas Instruments, “MSP430FR58xx, MSP43059xx, MSP430FR68xx, and MSP430FR69xx Family User’s Guide”, MSP4305994 Datasheet, Oct. 2012 [Revised Jan. 2017].
[6] Texas Instruments, “DRV5053 Analog-Bipolar Hall Effect Sensor”, DRV5053 Datasheet, May 2014 [Revised Dec. 2015].
[7] Texas Instruments, “Single-Channel 3:1 Multiplexer and Demultiplexer”, TS5A3359 Datasheet, Oct 2005 [Revised Jan. 2016].
[8] Texas Instruments, “Logic Analog Multiplexers and Demultiplexers”, CDx4HC405x, CDx4HCT405x Datasheet, Nov. 1997 [Revised Feb. 2017].


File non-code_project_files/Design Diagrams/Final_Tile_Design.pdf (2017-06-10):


Scanned by CamScanner


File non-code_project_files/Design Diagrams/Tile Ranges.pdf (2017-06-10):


Scanned by CamScanner

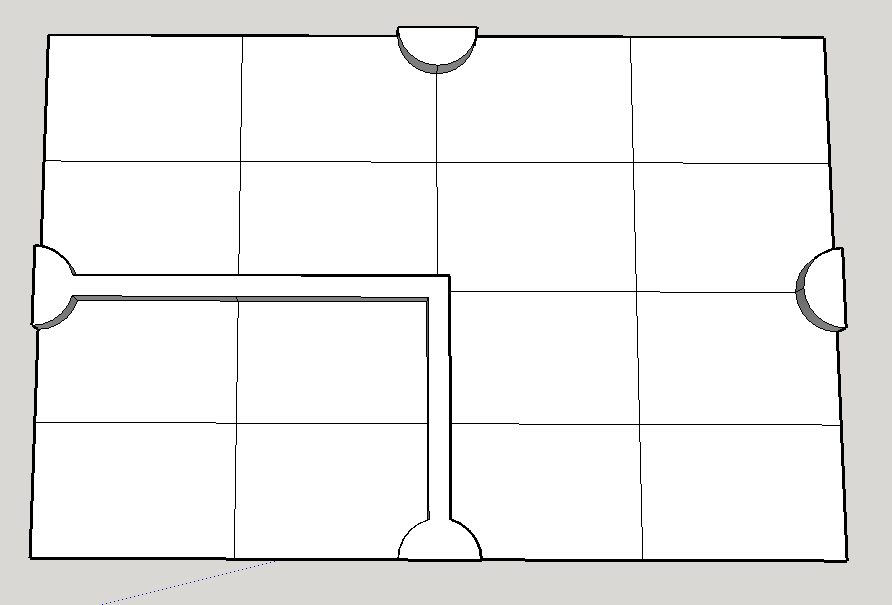
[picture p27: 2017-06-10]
non-code_project_files/Design Diagrams/3D tile design pics/Wire_12_3.PNG

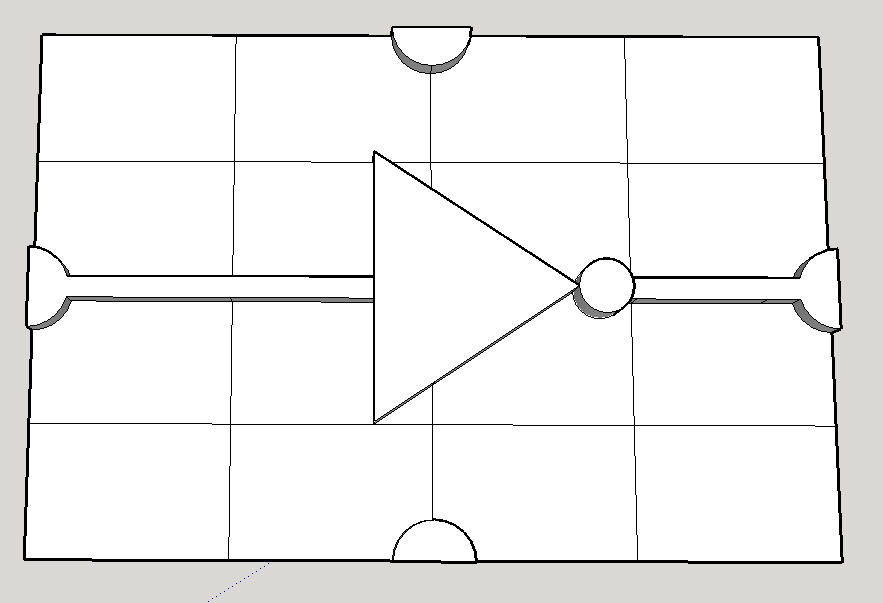
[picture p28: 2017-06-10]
non-code_project_files/Design Diagrams/3D tile design pics/NOT.PNG

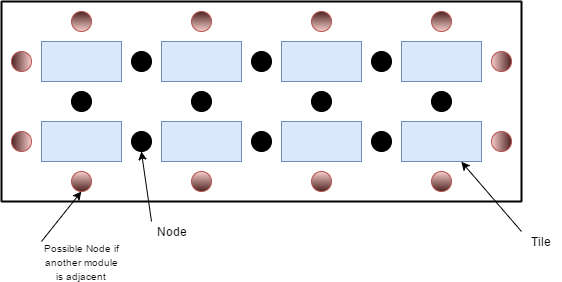
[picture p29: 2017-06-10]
non-code_project_files/Design Diagrams/Node Placement.png

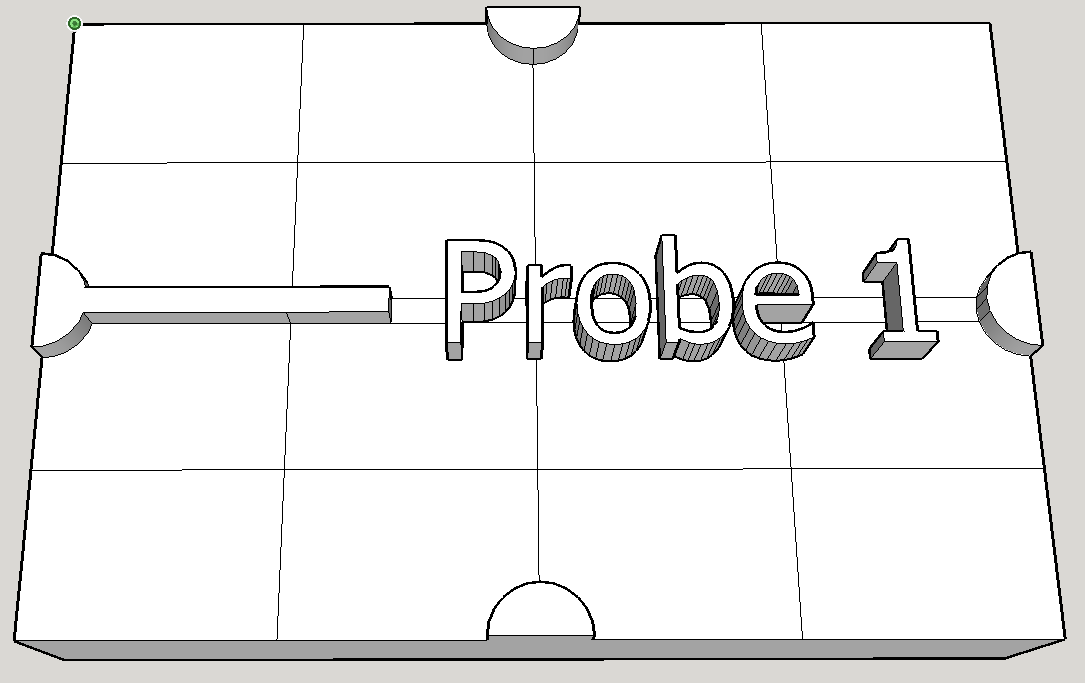
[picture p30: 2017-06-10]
non-code_project_files/Design Diagrams/3D tile design pics/Probe.PNG

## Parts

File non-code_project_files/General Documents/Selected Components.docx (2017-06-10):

8:1 MUX

https://www.digikey.com/product-detail/en/texas-instruments/CD74HC4051M96/296-14530-1-ND/555578

3:1 MUX

https://www.digikey.com/product-detail/en/texas-instruments/TS5A3359DCUR/296-21193-1-ND/1217100

Hall Effect Sensor

https://www.digikey.com/product-detail/en/texas-instruments/DRV5053VAQDBZR/296-38460-6-ND/5022242

Cap

https://www.digikey.com/product-detail/en/C0603C104J4RACTU/399-1097-1-ND/411372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

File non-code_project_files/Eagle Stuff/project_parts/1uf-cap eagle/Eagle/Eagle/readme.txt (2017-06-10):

 

**********************************************************
*************  Important Instructions Follow  ************
**********************************************************
 
All files exported to: C:\EMA\ExportFolder\35497\Output\Eagle\Eagle\Eagle.xml

To import your new library into Eagle:
1. Start Eagle.
2. Select File -> New -> Library from the menu.
3. In the blank library window, select File -> Execute Script from the menu.
5. Browse to your newly exported Eagle Script file (".scr" file extension)
6. After opening the file, the script will populate the new library.
7. Use File -> Save (or Save As..) to save the library to the desired location in Eagle native format.

For additional information, please visit this site:
http://www.accelerated-designs.com/help/Eagle_import.html

You may also find this video helpful:
http://youtu.be/5jGuWY-Yy3Q

Component "C0603C104J4RACTU" renamed to "C0603C104J4RACTU"

Ultra Librarian Gold 8.1.269 Process Report

Message - Padstack "RX34Y32D0T" Shape(4) is a CIRCLE with no diameter.
Message - Padstack "RX42Y36D0T" Shape(4) is a CIRCLE with no diameter.
Message - Padstack "RX26Y32D0T" Shape(4) is a CIRCLE with no diameter.

TextStyle count:  27
Padstack count:   3
Pattern count:    3
Symbol count:     2
Component count:  1

Export

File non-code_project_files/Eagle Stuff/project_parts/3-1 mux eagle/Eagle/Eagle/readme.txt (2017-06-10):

 

**********************************************************
*************  Important Instructions Follow  ************
**********************************************************
 
All files exported to: C:\EMA\ExportFolder\35485\Output\Eagle\Eagle\Eagle.xml

To import your new library into Eagle:
1. Start Eagle.
2. Select File -> New -> Library from the menu.
3. In the blank library window, select File -> Execute Script from the menu.
5. Browse to your newly exported Eagle Script file (".scr" file extension)
6. After opening the file, the script will populate the new library.
7. Use File -> Save (or Save As..) to save the library to the desired location in Eagle native format.

For additional information, please visit this site:
http://www.accelerated-designs.com/help/Eagle_import.html

You may also find this video helpful:
http://youtu.be/5jGuWY-Yy3Q

Component "TS5A3359DCUR" renamed to "TS5A3359DCUR"

Ultra Librarian Gold 8.1.269 Process Report

Message - Padstack "RX34Y10D0T" Shape(4) is a CIRCLE with no diameter.
Message - Padstack "RX58Y10D0T" Shape(4) is a CIRCLE with no diameter.
Message - Padstack "RX46Y10D0T" Shape(4) is a CIRCLE with no diameter.

TextStyle count:  25
Padstack count:   3
Pattern count:    3
Symbol count:     1
Component count:  1

Export

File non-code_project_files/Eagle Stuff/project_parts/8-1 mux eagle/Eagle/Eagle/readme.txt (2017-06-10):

 

**********************************************************
*************  Important Instructions Follow  ************
**********************************************************
 
All files exported to: C:\EMA\ExportFolder\35480\Output\Eagle\Eagle\Eagle.xml

To import your new library into Eagle:
1. Start Eagle.
2. Select File -> New -> Library from the menu.
3. In the blank library window, select File -> Execute Script from the menu.
5. Browse to your newly exported Eagle Script file (".scr" file extension)
6. After opening the file, the script will populate the new library.
7. Use File -> Save (or Save As..) to save the library to the desired location in Eagle native format.

For additional information, please visit this site:
http://www.accelerated-designs.com/help/Eagle_import.html

You may also find this video helpful:
http://youtu.be/5jGuWY-Yy3Q

Component "CD74HC4051M96" renamed to "CD74HC4051M96"

Ultra Librarian Gold 8.1.269 Process Report

Message - Padstack "RX74Y20D0T" Shape(4) is a CIRCLE with no diameter.
Message - Padstack "RX98Y24D0T" Shape(4) is a CIRCLE with no diameter.
Message - Padstack "RX86Y22D0T" Shape(4) is a CIRCLE with no diameter.

TextStyle count:  25
Padstack count:   3
Pattern count:    3
Symbol count:     1
Component count:  1

Export

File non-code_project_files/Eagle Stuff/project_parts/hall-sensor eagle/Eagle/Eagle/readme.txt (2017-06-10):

 

**********************************************************
*************  Important Instructions Follow  ************
**********************************************************
 
All files exported to: C:\EMA\ExportFolder\35489\Output\Eagle\Eagle\Eagle.xml

To import your new library into Eagle:
1. Start Eagle.
2. Select File -> New -> Library from the menu.
3. In the blank library window, select File -> Execute Script from the menu.
5. Browse to your newly exported Eagle Script file (".scr" file extension)
6. After opening the file, the script will populate the new library.
7. Use File -> Save (or Save As..) to save the library to the desired location in Eagle native format.

For additional information, please visit this site:
http://www.accelerated-designs.com/help/Eagle_import.html

You may also find this video helpful:
http://youtu.be/5jGuWY-Yy3Q

Component "DRV5053VAQDBZR" renamed to "DRV5053VAQDBZR"

Ultra Librarian Gold 8.1.269 Process Report

Message - Padstack "RX22Y62p5D0T" Shape(4) is a CIRCLE with no diameter.
Message - Padstack "RX24Y64D0T" Shape(4) is a CIRCLE with no diameter.
Message - Padstack "RX24Y74p5D0T" Shape(4) is a CIRCLE with no diameter.
Message - Padstack "RX20Y40D0T" Shape(4) is a CIRCLE with no diameter.
Message - Padstack "RX20Y50p5D0T" Shape(4) is a CIRCLE with no diameter.
Message - Padstack "RX22Y52D0T" Shape(4) is a CIRCLE with no diameter.

TextStyle count:  25
Padstack count:   6
Pattern count:    3
Symbol count:     1
Component count:  1

Export

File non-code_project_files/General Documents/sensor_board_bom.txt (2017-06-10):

Partlist exported from C:/Users/twlen/Desktop/sensor_board.sch at 4/24/2017 8:13 PM

Qty Value                     Device                    Package    Parts                                                                                                                                                                  Description                          MANUFACTURER_PART_NUMBER MF    MPN        OC_FARNELL OC_NEWARK VENDOR           
28  C0603C104J4RACTU          C0603C104J4RACTU          CC0603N    C1, C2, C3, C4, C5, C6, C7, C8, C9, C10, C11, C12, C13, C14, C15, C16, C17, C18, C19, C20, C21, C22, C23, C24, C25, C26, C27, C28                                                                               C0603C104J4RACTU                                               Kemet                                                                                                                                                                                                                 C0603C104J4RACTU                                               Kemet            
3   CD74HC4051M96D16-M        CD74HC4051M96D16-M        D16-M      TILE_MAG0, TILE_MAG1, TILE_MAG2                                                                                                                                                                             CD74HC4051M96                                                  Texas Instruments
24  DRV5053VAQDBZRDBZ3-M      DRV5053VAQDBZRDBZ3-M      DBZ3-M     T0_M0, T0_M1, T0_M2, T1_M0, T1_M1, T1_M2, T2_M0, T2_M1, T2_M2, T3_M0, T3_M1, T3_M2, T4_M0, T4_M1, T4_M2, T5_M0, T5_M1, T5_M2, T6_M0, T6_M1, T6_M2, T7_M0, T7_M1, T7_M2                                      drv5053vaqdbzr                                                 Texas Instruments
1   TS5A3359DCUR              TS5A3359DCUR              DCU8       MAG_MUX                                                                                                                                                                                                     TS5A3359DCUR                                                   Texas Instruments

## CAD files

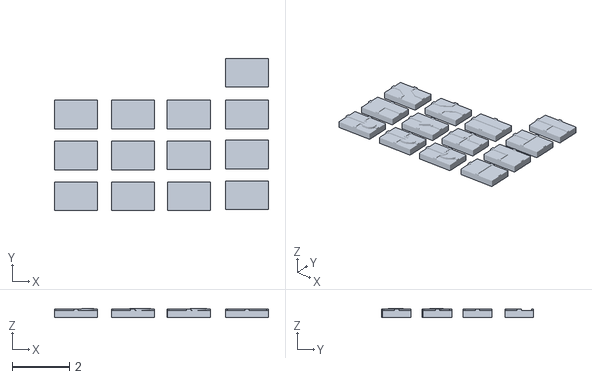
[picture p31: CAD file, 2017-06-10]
non-code_project_files/3D CAD Stuff/Tile_Designs.stl
7.45 x 5.30 x 0.33

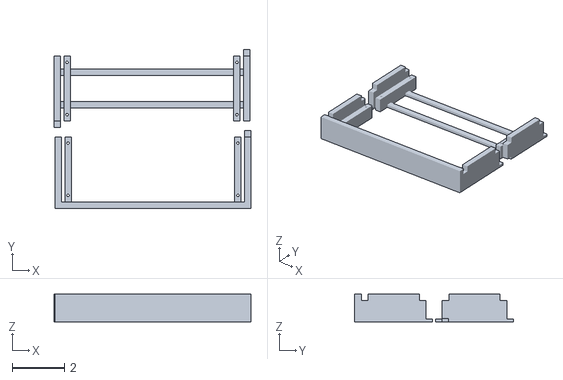
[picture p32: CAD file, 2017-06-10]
non-code_project_files/3D CAD Stuff/Triple_Module_Frame.stl
7.54 x 6.08 x 1.06

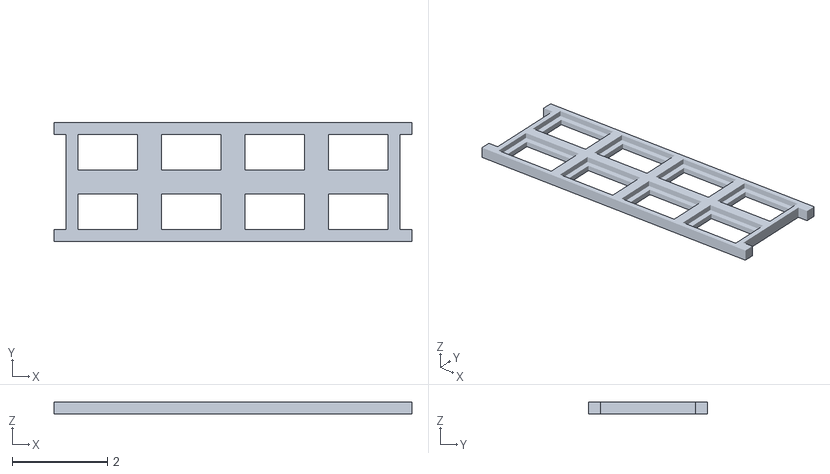
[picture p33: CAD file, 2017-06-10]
non-code_project_files/3D CAD Stuff/Single_Module_Mount_Top.stl
7.50 x 2.50 x 0.25

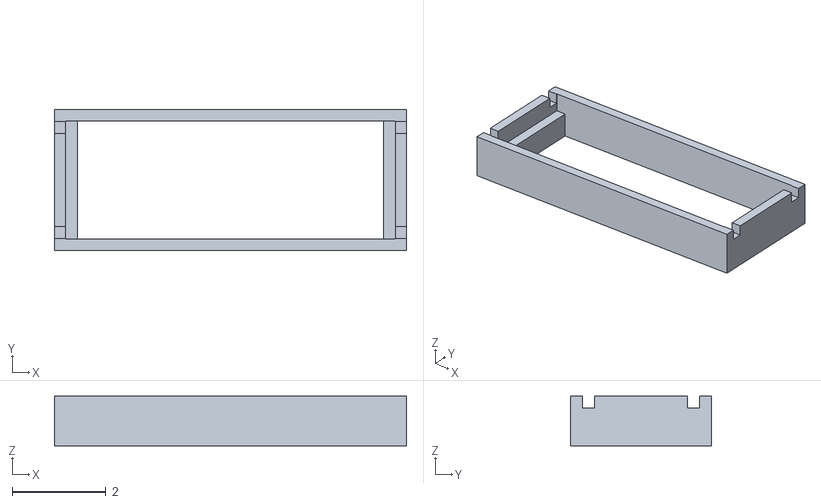
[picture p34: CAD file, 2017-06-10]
non-code_project_files/3D CAD Stuff/Single_Module_Mount_Bottom.stl
7.50 x 3.00 x 1.06

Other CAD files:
non-code_project_files/3D CAD Stuff/Tile_Designs.skp
non-code_project_files/3D CAD Stuff/Triple_Module_Frame.skp

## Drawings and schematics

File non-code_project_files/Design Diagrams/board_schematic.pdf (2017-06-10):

A

## BCD

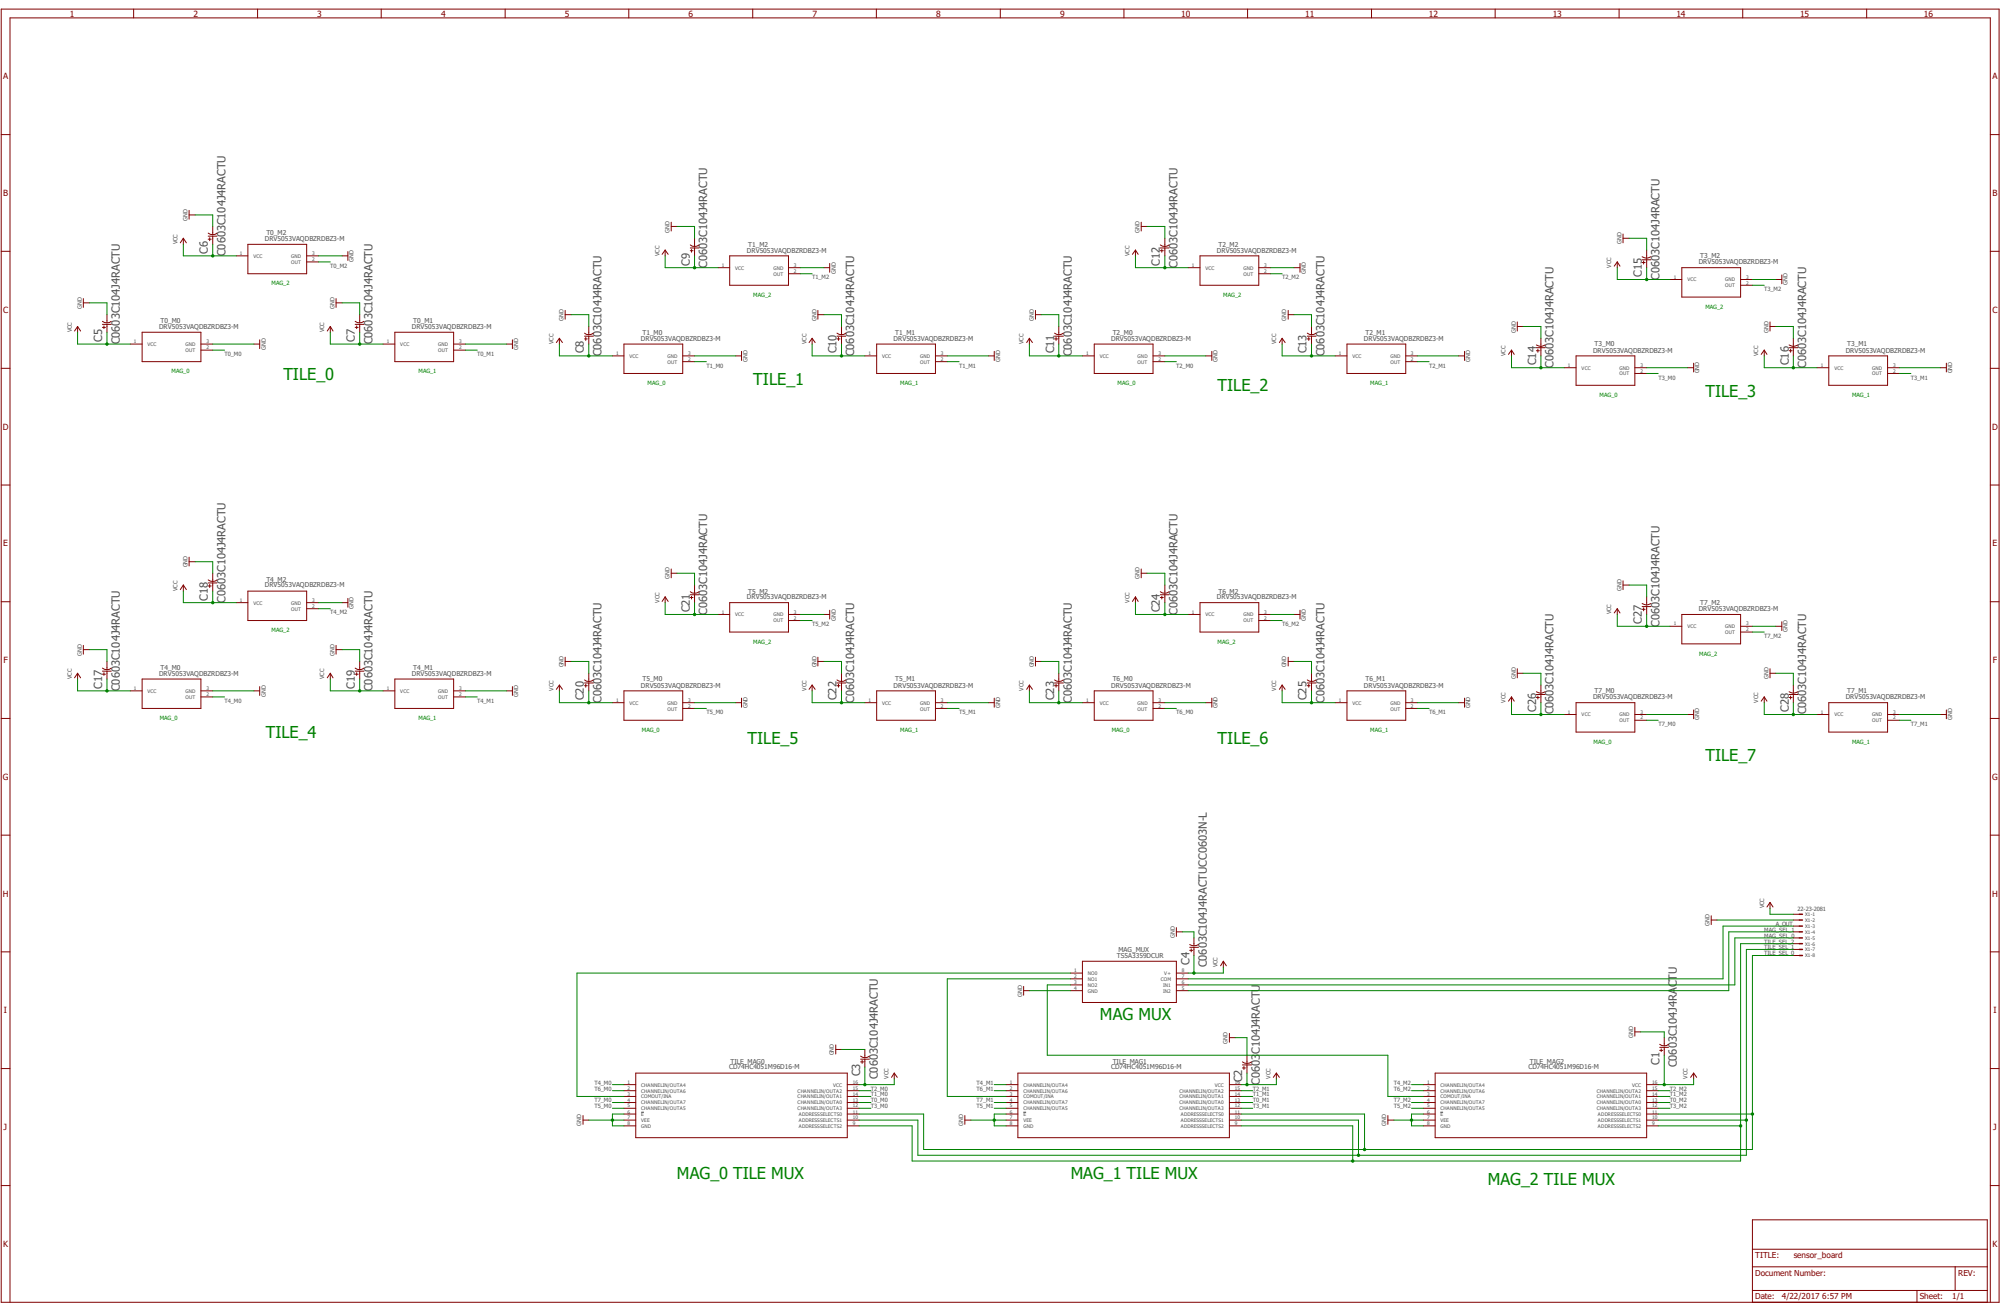
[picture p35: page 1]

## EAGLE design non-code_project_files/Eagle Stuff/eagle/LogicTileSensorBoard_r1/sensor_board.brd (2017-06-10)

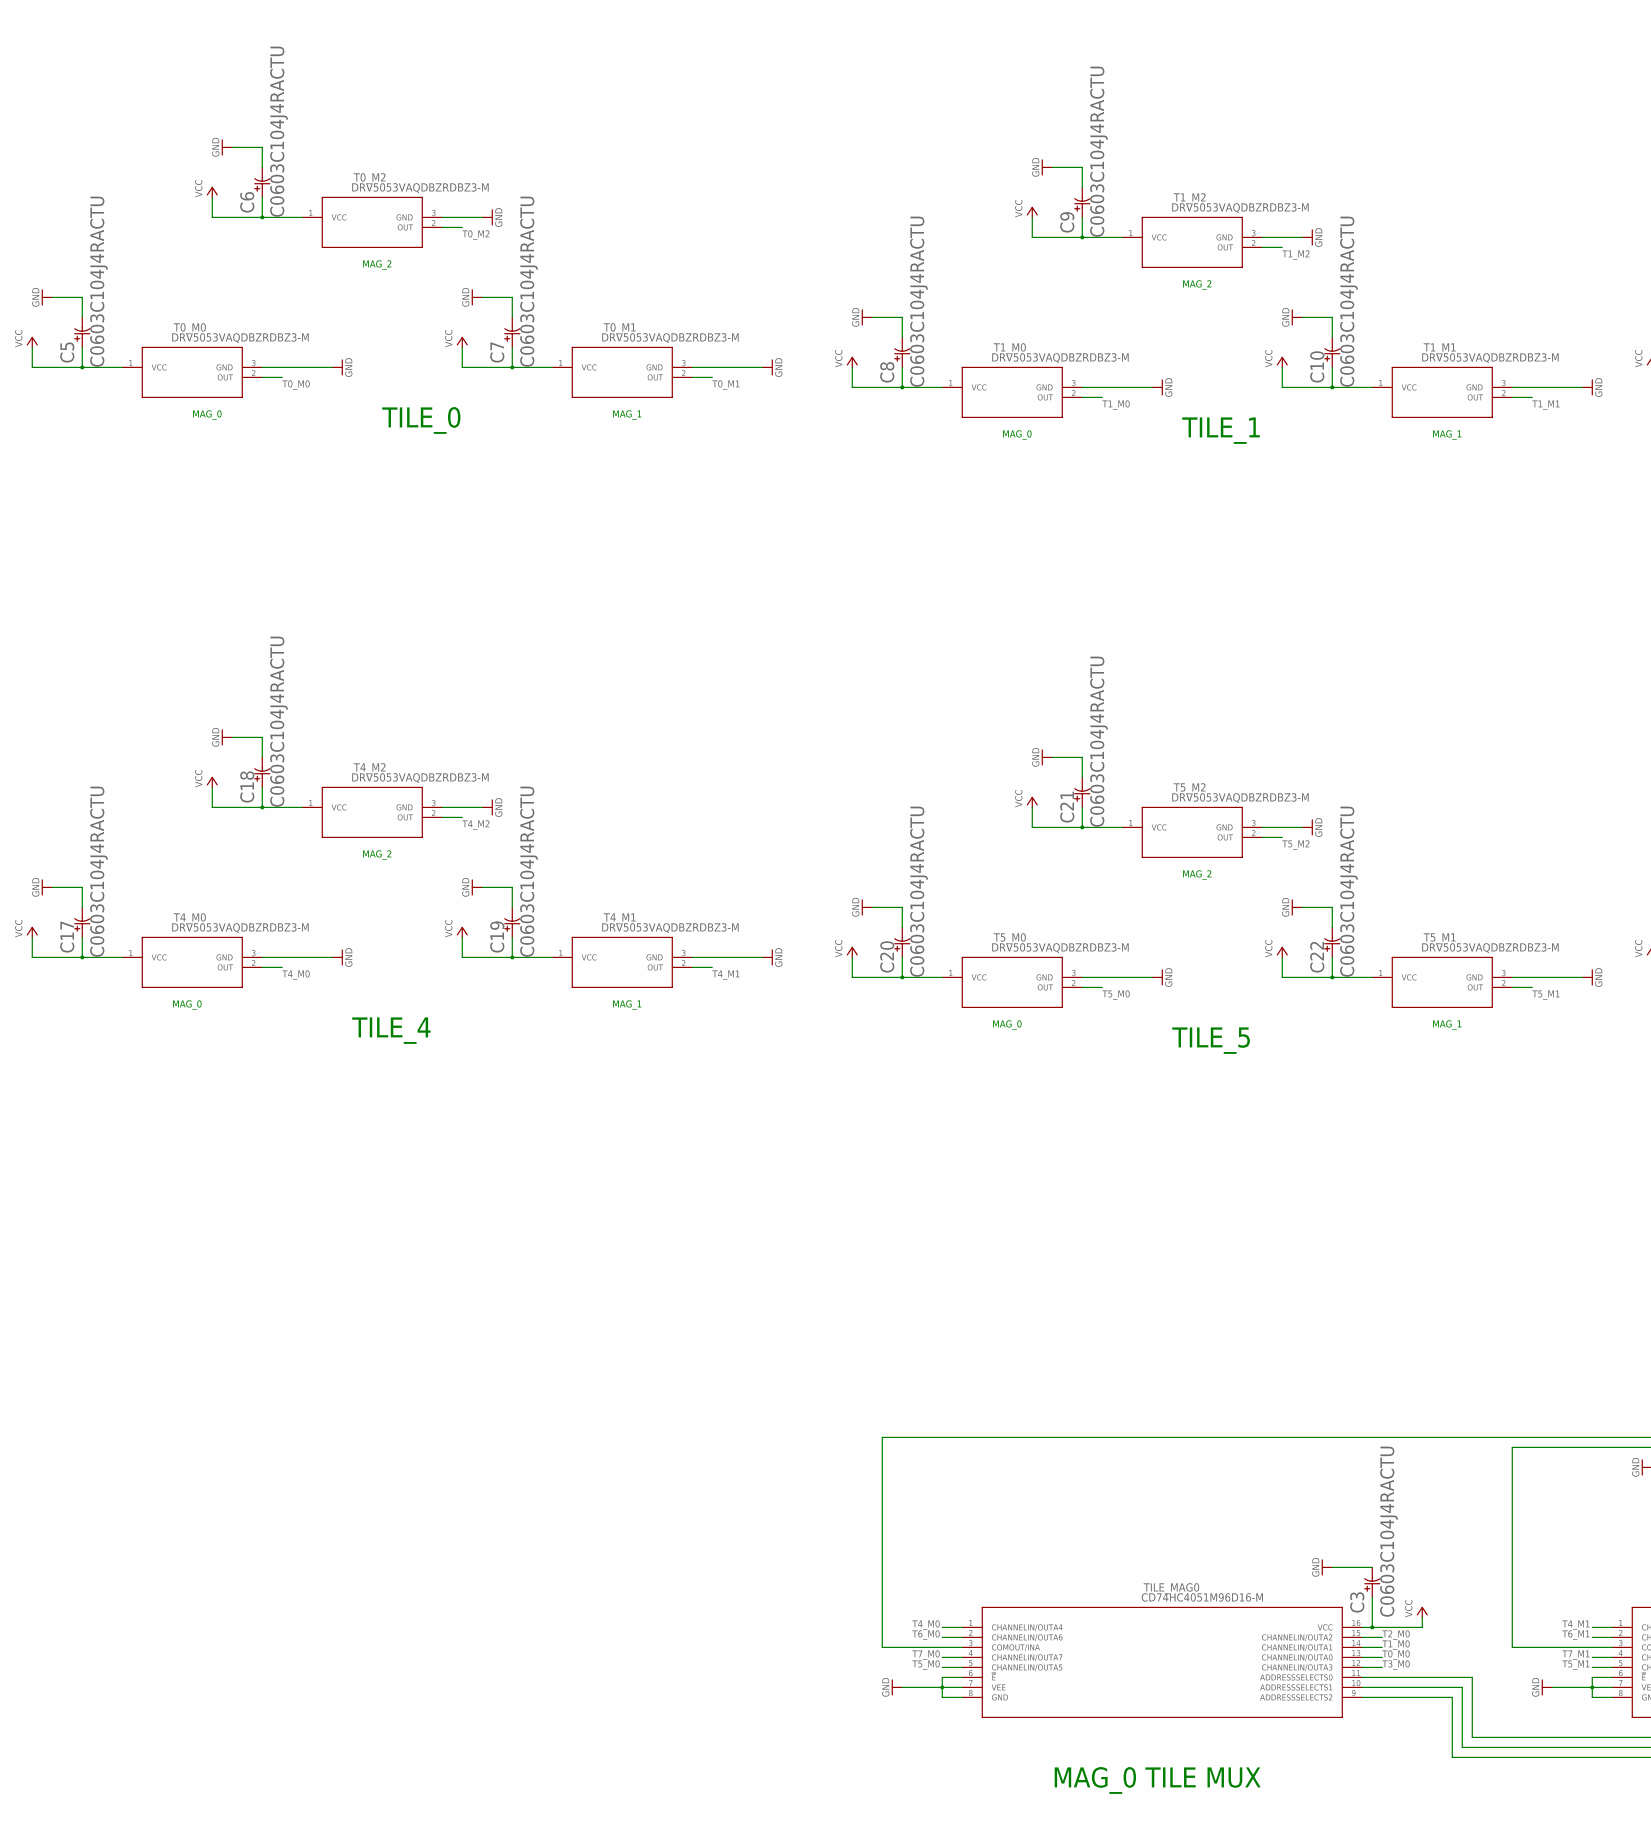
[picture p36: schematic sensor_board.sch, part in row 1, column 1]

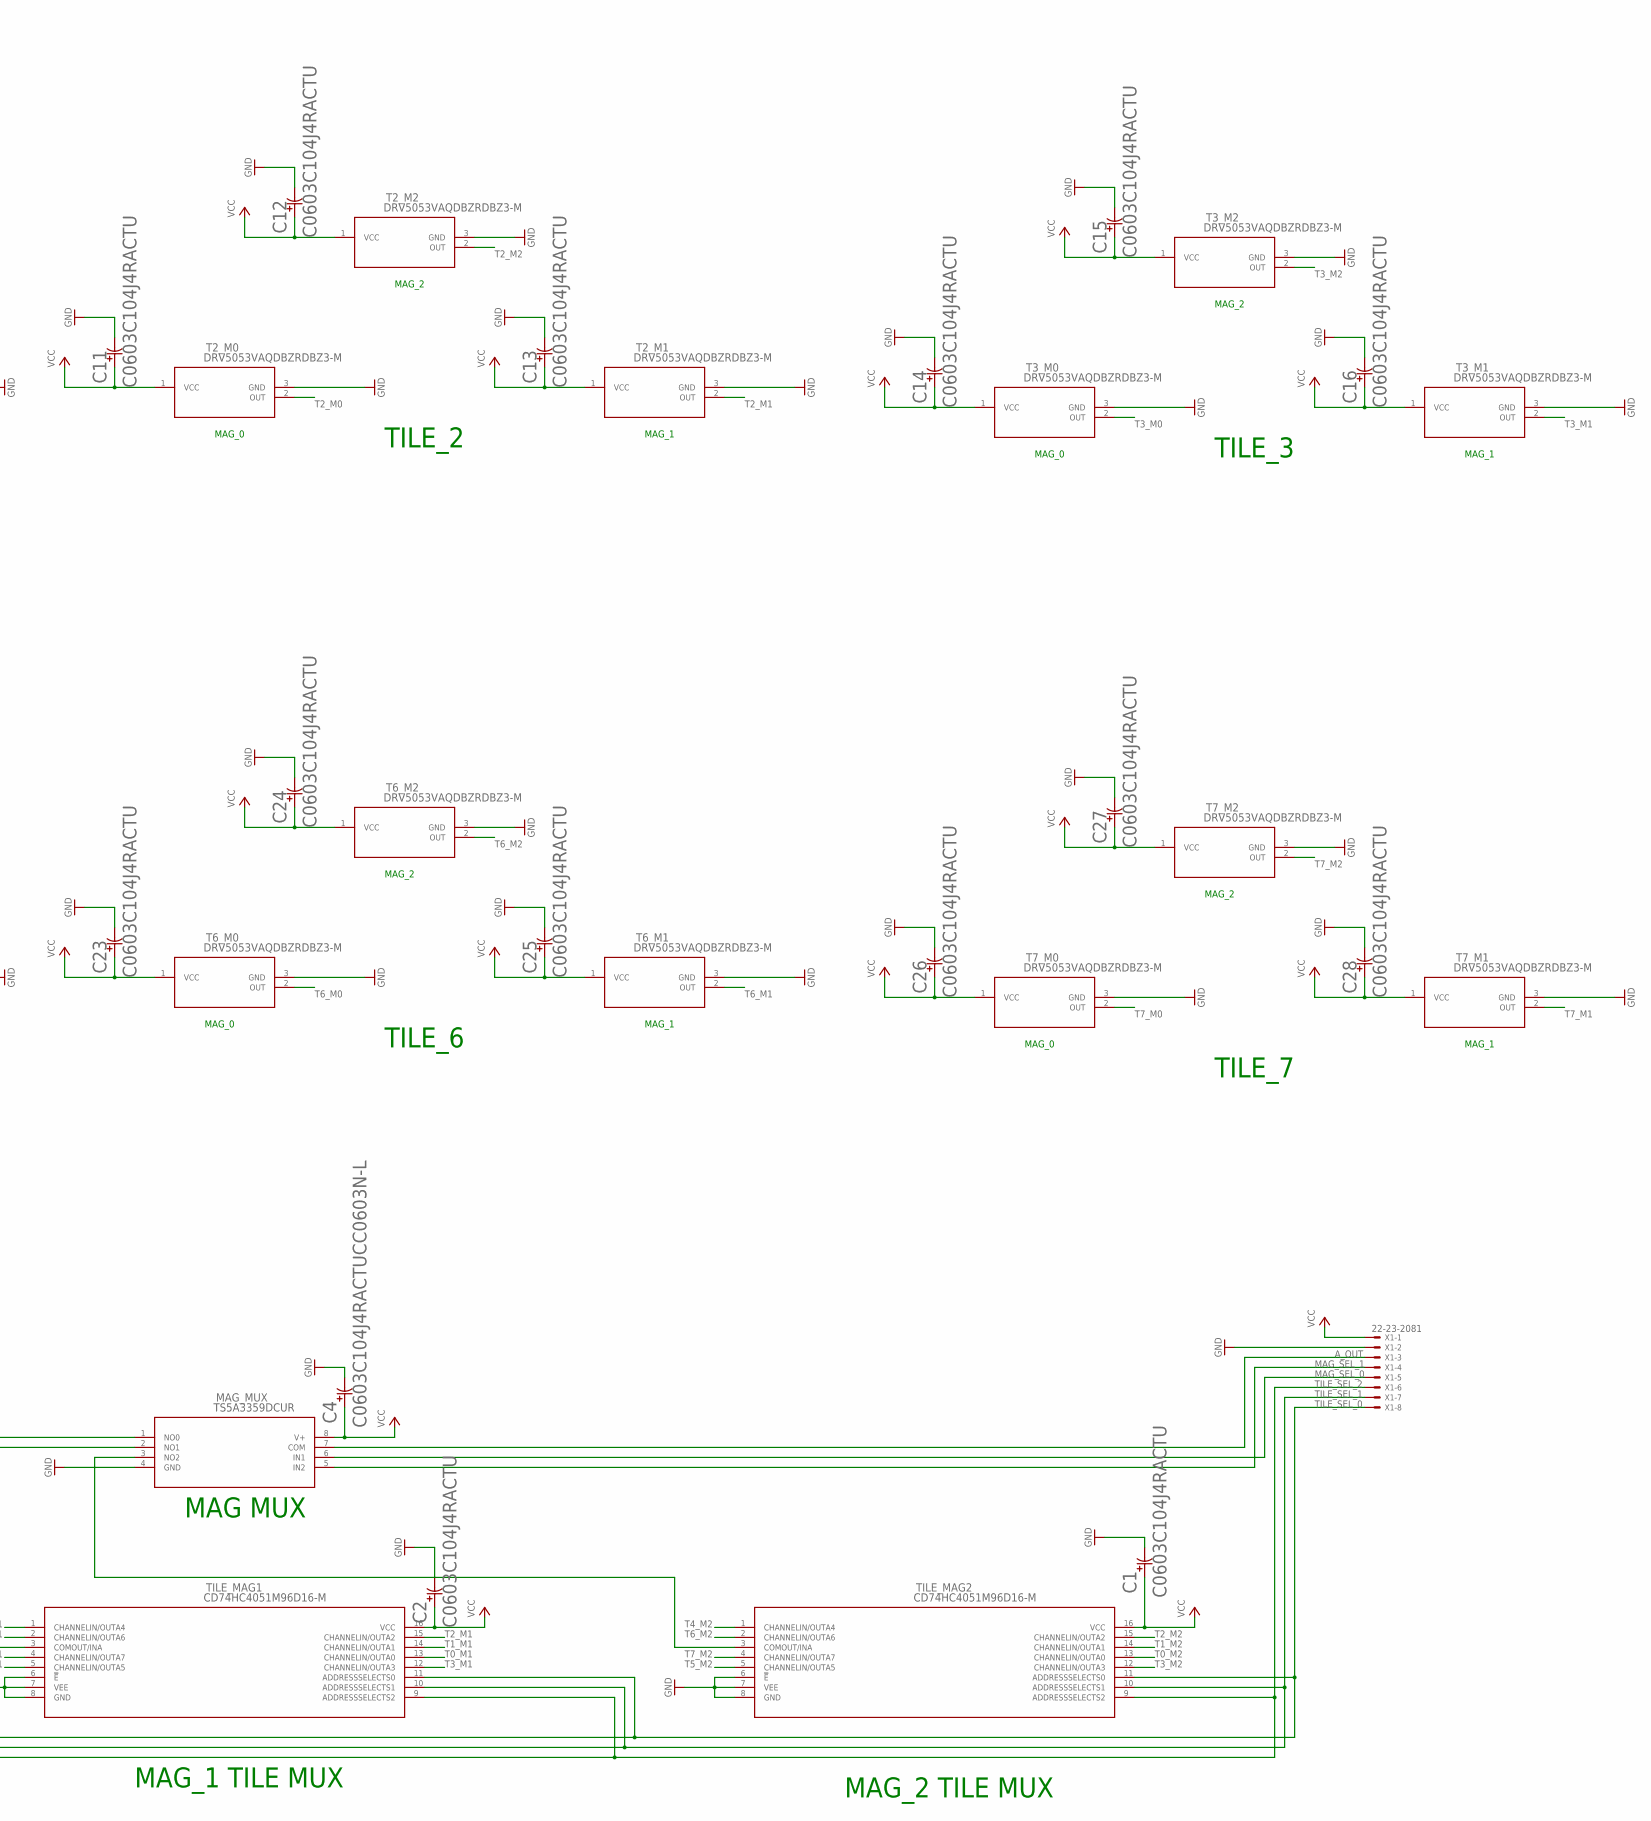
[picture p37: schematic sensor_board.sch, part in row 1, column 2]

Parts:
C1, C2, C3, C5, C6, C7, C8, C9, C10, C11, C12, C13, C14, C15, C16, C17, C18, C19, C20, C21, C22, C23, C24, C25, C26, C27, C28: C0603C104J4RACTU; CC0603N
C4: C0603C104J4RACTUCC0603N-L; CC0603N-L
MAG_MUX: TS5A3359DCUR; DCU8
T0_M0, T0_M1, T0_M2, T1_M0, T1_M1, T1_M2, T2_M0, T2_M1, T2_M2, T3_M0, T3_M1, T3_M2, T4_M0, T4_M1, T4_M2, T5_M0, T5_M1, T5_M2, T6_M0, T6_M1, T6_M2, T7_M0, T7_M1, T7_M2: DRV5053VAQDBZRDBZ3-M; DBZ3-M
TILE_MAG0, TILE_MAG1, TILE_MAG2: CD74HC4051M96D16-M; D16-M
X1: 22-23-2081

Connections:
A_OUT: MAG_MUX.7 (COM), X1.3
GND: C1.2 (22), C2.2 (22), C3.2 (22), C4.2 (22), C5.2 (22), C6.2 (22), C7.2 (22), C8.2 (22), C9.2 (22), C10.2 (22), C11.2 (22), C12.2 (22), C13.2 (22), C14.2 (22), C15.2 (22), C16.2 (22), C17.2 (22), C18.2 (22), C19.2 (22), C20.2 (22), C21.2 (22), C22.2 (22), C23.2 (22), C24.2 (22), C25.2 (22), C26.2 (22), C27.2 (22), C28.2 (22), MAG_MUX.4 (GND), T0_M0.3 (GND), T0_M1.3 (GND), T0_M2.3 (GND), T1_M0.3 (GND), T1_M1.3 (GND), T1_M2.3 (GND), T2_M0.3 (GND), T2_M1.3 (GND), T2_M2.3 (GND), T3_M0.3 (GND), T3_M1.3 (GND), T3_M2.3 (GND), T4_M0.3 (GND), T4_M1.3 (GND), T4_M2.3 (GND), T5_M0.3 (GND), T5_M1.3 (GND), T5_M2.3 (GND), T6_M0.3 (GND), T6_M1.3 (GND), T6_M2.3 (GND), T7_M0.3 (GND), T7_M1.3 (GND), T7_M2.3 (GND), TILE_MAG0.6 (!E), TILE_MAG0.7 (VEE), TILE_MAG0.8 (GND), TILE_MAG1.6 (!E), TILE_MAG1.7 (VEE), TILE_MAG1.8 (GND), TILE_MAG2.6 (!E), TILE_MAG2.7 (VEE), TILE_MAG2.8 (GND), X1.2
MAG_SEL_0: MAG_MUX.6 (IN1), X1.5
MAG_SEL_1: MAG_MUX.5 (IN2), X1.4
unnamed: MAG_MUX.1 (NO0), TILE_MAG0.3 (COMOUT/INA)
unnamed: MAG_MUX.2 (NO1), TILE_MAG1.3 (COMOUT/INA)
unnamed: MAG_MUX.3 (NO2), TILE_MAG2.3 (COMOUT/INA)
T0_M0: T0_M0.2 (OUT), TILE_MAG0.13 (CHANNELIN/OUTA0)
T0_M1: T0_M1.2 (OUT), TILE_MAG1.13 (CHANNELIN/OUTA0)
T0_M2: T0_M2.2 (OUT), TILE_MAG2.13 (CHANNELIN/OUTA0)
T1_M0: T1_M0.2 (OUT), TILE_MAG0.14 (CHANNELIN/OUTA1)
T1_M1: T1_M1.2 (OUT), TILE_MAG1.14 (CHANNELIN/OUTA1)
T1_M2: T1_M2.2 (OUT), TILE_MAG2.14 (CHANNELIN/OUTA1)
T2_M0: T2_M0.2 (OUT), TILE_MAG0.15 (CHANNELIN/OUTA2)
T2_M1: T2_M1.2 (OUT), TILE_MAG1.15 (CHANNELIN/OUTA2)
T2_M2: T2_M2.2 (OUT), TILE_MAG2.15 (CHANNELIN/OUTA2)
T3_M0: T3_M0.2 (OUT), TILE_MAG0.12 (CHANNELIN/OUTA3)
T3_M1: T3_M1.2 (OUT), TILE_MAG1.12 (CHANNELIN/OUTA3)
T3_M2: T3_M2.2 (OUT), TILE_MAG2.12 (CHANNELIN/OUTA3)
T4_M0: T4_M0.2 (OUT), TILE_MAG0.1 (CHANNELIN/OUTA4)
T4_M1: T4_M1.2 (OUT), TILE_MAG1.1 (CHANNELIN/OUTA4)
T4_M2: T4_M2.2 (OUT), TILE_MAG2.1 (CHANNELIN/OUTA4)
T5_M0: T5_M0.2 (OUT), TILE_MAG0.5 (CHANNELIN/OUTA5)
T5_M1: T5_M1.2 (OUT), TILE_MAG1.5 (CHANNELIN/OUTA5)
T5_M2: T5_M2.2 (OUT), TILE_MAG2.5 (CHANNELIN/OUTA5)
T6_M0: T6_M0.2 (OUT), TILE_MAG0.2 (CHANNELIN/OUTA6)
T6_M1: T6_M1.2 (OUT), TILE_MAG1.2 (CHANNELIN/OUTA6)
T6_M2: T6_M2.2 (OUT), TILE_MAG2.2 (CHANNELIN/OUTA6)
T7_M0: T7_M0.2 (OUT), TILE_MAG0.4 (CHANNELIN/OUTA7)
T7_M1: T7_M1.2 (OUT), TILE_MAG1.4 (CHANNELIN/OUTA7)
T7_M2: T7_M2.2 (OUT), TILE_MAG2.4 (CHANNELIN/OUTA7)
TILE_SEL_0: TILE_MAG0.11 (ADDRESSSELECTS0), TILE_MAG1.11 (ADDRESSSELECTS0), TILE_MAG2.11 (ADDRESSSELECTS0), X1.8
TILE_SEL_1: TILE_MAG0.10 (ADDRESSSELECTS1), TILE_MAG1.10 (ADDRESSSELECTS1), TILE_MAG2.10 (ADDRESSSELECTS1), X1.7
TILE_SEL_2: TILE_MAG0.9 (ADDRESSSELECTS2), TILE_MAG1.9 (ADDRESSSELECTS2), TILE_MAG2.9 (ADDRESSSELECTS2), X1.6
VCC: C1.1 (11), C2.1 (11), C3.1 (11), C4.1 (11), C5.1 (11), C6.1 (11), C7.1 (11), C8.1 (11), C9.1 (11), C10.1 (11), C11.1 (11), C12.1 (11), C13.1 (11), C14.1 (11), C15.1 (11), C16.1 (11), C17.1 (11), C18.1 (11), C19.1 (11), C20.1 (11), C21.1 (11), C22.1 (11), C23.1 (11), C24.1 (11), C25.1 (11), C26.1 (11), C27.1 (11), C28.1 (11), MAG_MUX.8 (V+), T0_M0.1 (VCC), T0_M1.1 (VCC), T0_M2.1 (VCC), T1_M0.1 (VCC), T1_M1.1 (VCC), T1_M2.1 (VCC), T2_M0.1 (VCC), T2_M1.1 (VCC), T2_M2.1 (VCC), T3_M0.1 (VCC), T3_M1.1 (VCC), T3_M2.1 (VCC), T4_M0.1 (VCC), T4_M1.1 (VCC), T4_M2.1 (VCC), T5_M0.1 (VCC), T5_M1.1 (VCC), T5_M2.1 (VCC), T6_M0.1 (VCC), T6_M1.1 (VCC), T6_M2.1 (VCC), T7_M0.1 (VCC), T7_M1.1 (VCC), T7_M2.1 (VCC), TILE_MAG0.16 (VCC), TILE_MAG1.16 (VCC), TILE_MAG2.16 (VCC), X1.1

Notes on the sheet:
TILE_0
TILE_1
TILE_2
TILE_3
TILE_4
TILE_5
TILE_6
TILE_7
MAG_0
MAG_2
MAG_1
MAG_0 TILE MUX
MAG_1 TILE MUX
MAG_2 TILE MUX
MAG MUX

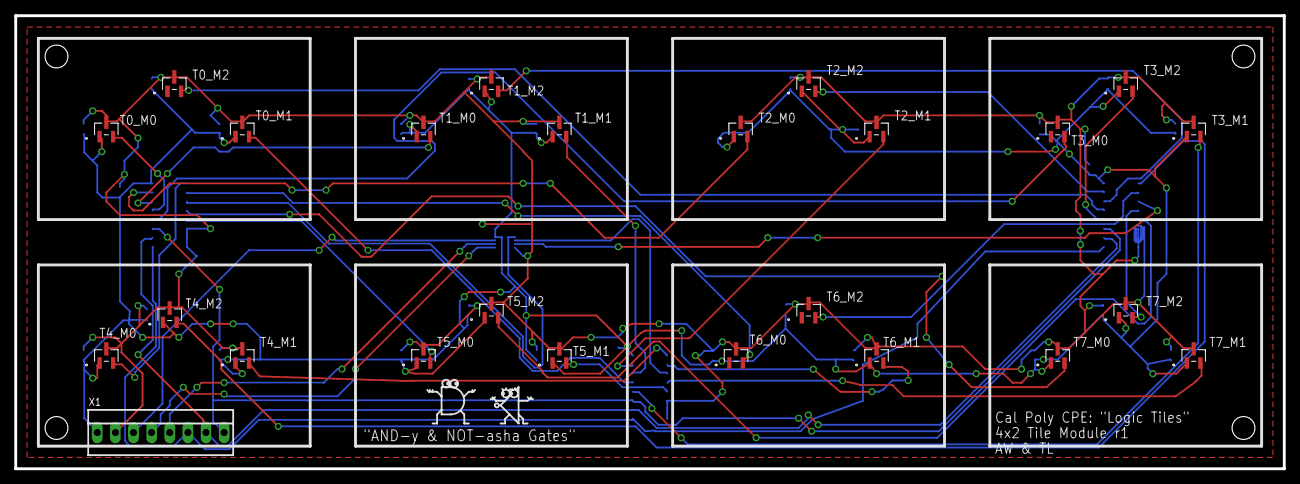
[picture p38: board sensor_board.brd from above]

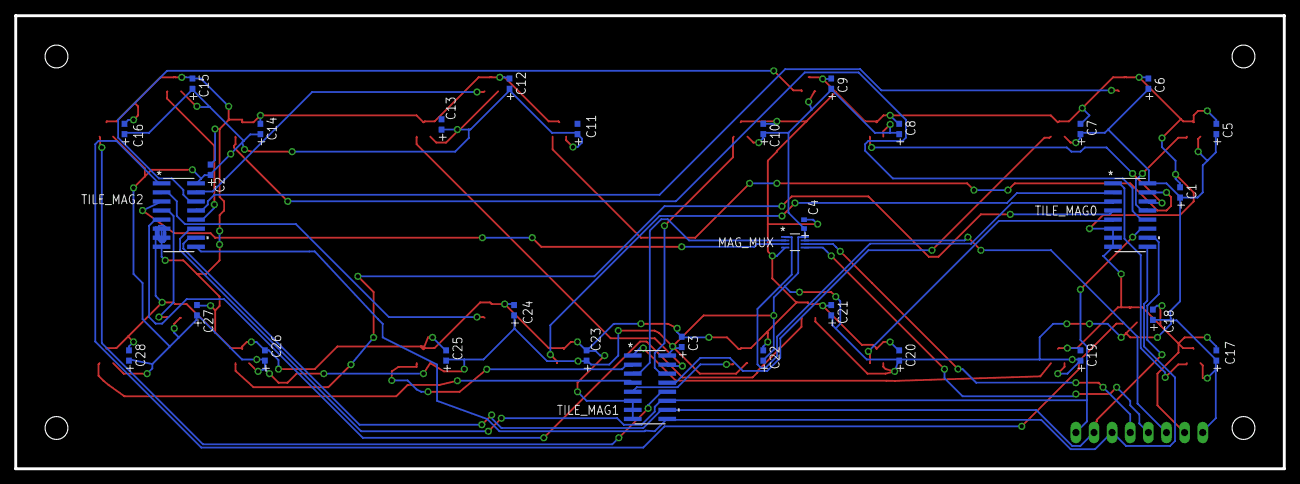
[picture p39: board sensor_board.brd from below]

Board: 2 copper layers, 177.8 x 63.5 mm, 57 parts (32 on the bottom side), 35 nets.

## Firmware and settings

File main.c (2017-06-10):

//***************************************************************************************
// MSP430 Logic Tiles Project - main.c
// Spring 2017 Senior Project
// Cal Poly CPE Department
//
// The Main Loop State Machine, initializations, terminal commands, and ISRs
//
// Authors: Tristan Lennertz & Andrew Wheeler
//***************************************************************************************

#include <msp430.h>
#include "main.h"
#include "tiles.h"
#include "graph.h"
#include <stdint.h>
#include <string.h>

/* Uncomment in to put in debugging mode, which prints a lot of status stuff as it happens */
//#define _DEBUG_ON

/* Uncomment for massive runtime dump of every ADC read (for determining magnet value ranges */
//#define _ADC_DUMP

/* Current Values of the Source Blocks */
digiVal currSourceA = ZERO;
digiVal currSourceB = ZERO;
digiVal currSourceC = ZERO;
digiVal currSourceD = ZERO;

/* Current Nodes and Tiles of Probe Blocks */
Node *currProbeANode = NULL;
Node *currProbeBNode = NULL;
Node *currProbeCNode = NULL;
Node *currProbeDNode = NULL;

TileState *currProbeATile = NULL;
TileState *currProbeBTile = NULL;
TileState *currProbeCTile = NULL;
TileState *currProbeDTile = NULL;

/* Holds last read value of ADC for each module's output to an ADC pin */
static volatile uint16_t lastReadADCValue = 0;

/* RX receive buffer */
#define RX_BUFFER_SIZE 150
static char uBuff[RX_BUFFER_SIZE + 1];
static volatile unsigned int buffIndex = 0;
static char lastRXChar;

/* TX ring buffer */
#define PRINT_BUFFER_SIZE 500
static char printBuff[PRINT_BUFFER_SIZE];
static unsigned int ringNdx = 0;
static unsigned int printNdx = 0;
static unsigned int numPendingTX = 0;

/*Flags*/
static volatile char rxPending = 0;
static volatile char adcRead = 0;

/* The currently known states of the tiles on the board */
static TileState tileStates[NUM_TILES];

int main(void) {
    init();
    __enable_interrupt();

    uPrint("\r\nLogic Tiles Version 0.1");
    printCmds();
    uPrint(">: ");

    /* Main state machine loop */
    state currentState = IDLE_POLL;
    for(;;) {

        switch (currentState) {

        case IDLE_POLL:
            currentState = idlePoll();
            break;

        case CMD_PARSE:
            currentState = cmdParse();
            break;

        case UPDATE_CKT:
            /* call printProbes here, or something similar. Right now we just have printProbes
             * called manually via terminal */
            currentState = IDLE_POLL;
            break;

        default:
            break;
        }
    }
}

/* Checks for a pending serial communication and dispatches to a processing state if detected.
 * Otherwise moves on to polling for changed tile states on the board. If a changed tile is
 * found, dispatches to an updating of the circuit state. Otherwise defaults to this state for
 * next state. */
state idlePoll() {
    int changedTile;
    state nextState = IDLE_POLL;

    if (rxPending) {
        rxPending = 0;
        nextState = CMD_PARSE;
    }
    else if ((changedTile = pollTiles(tileStates)) >= 0) {
        __delay_cycles(400000);

#ifdef _DEBUG_ON
        char tempBuff[50];
        sprintf(tempBuff, "\r\nTile Change : %d\r\n>: ", changedTile);
        uPrint(tempBuff);
#endif

        updateTile(changedTile, tileStates);
        insertTile(changedTile, tileStates);

        nextState = UPDATE_CKT;
    }
  
    return nextState;
}

/* Parses the RX buffer, checking for known commands. If a match is found,
 * dispatches to command function. Otherwise, just return */
state cmdParse() {
    char* bufPtr = uBuff;

#ifdef _DEBUG_ON
    uPrint("\r\nRead: ");
    uPrint(uBuff);
    uPrint("\r\n");
#endif

    uPrint("\r\n");

    if (*bufPtr && (*bufPtr == ' ' || *bufPtr == '\n' || *bufPtr == '\r'))
        bufPtr = nextToken(bufPtr);

    if (!strncmp(bufPtr, "set", 3)) {
       bufPtr = nextToken(bufPtr);
       setSource(*bufPtr);
    }
    else if (!strncmp(bufPtr, "clear", 4)) {
        bufPtr = nextToken(bufPtr);
        clearSource(*bufPtr);
    }
    else if (!strncmp(bufPtr, "printTiles", 10)) {
        printTiles();
    }
    else if (!strncmp(bufPtr, "run", 3)) {
        printProbes();
    }

    uPrint("\r\n>: ");

    return IDLE_POLL;
}

/* Runs through every TileState structure, printing its type and node id numbers
 * of each of its side nodes, if any */
void printTiles() {
    unsigned int i;
    char buffer[200];
    char bigBuff[150];

    uPrint("\r\n");

    for (i = 0; i < NUM_TILES; i++) {
        sprintf(buffer, "\tTile %d\t:\t", i);
        uPrint(buffer);

        char *typeStr;
        int l, r, t, b;
        l = r = t = b = 0;

        switch (tileStates[i].type) {
        case EMPTY:
            typeStr = "EMPTY";
            break;
        case AND:
            typeStr = "AND";
            break;
        case OR:
            typeStr = "OR";
            break;
        case XOR:
            typeStr = "XOR";
            break;
        case NOT:
            typeStr = "NOT";;
            break;
        case SOURCE_A:
            typeStr = "Source A";
            break;
        case SOURCE_B:
            typeStr = "Source B";
            break;
        case SOURCE_C:
            typeStr = "Source C";
            break;
        case SOURCE_D:
            typeStr = "SOURCE D";
            break;
        case PROBE_A:
            typeStr = "PROBE 1";
            break;
        case PROBE_B:
            typeStr = "PROBE 2";
            break;
        case PROBE_C:
            typeStr = "PROBE 3";
            break;
        case PROBE_D:
            typeStr = "PROBE 4";
            break;
        case HORIZONTAL:
            typeStr = "HORIZONTAL";
            break;
        case VERTICAL:
            typeStr = "VERTICAL";
            break;
        case WIRE_9_12:
            typeStr = "WIRE_9_12";
            break;
        case WIRE_12_3:
            typeStr = "WIRE_12_3";
            break;
        case JUMP:
            typeStr = "JUMP";
            break;
        case ULTRA_NODE:
            typeStr = "ULTRA_NODE";
            break;
        case WIRE_9_12_3:
            typeStr = "WIRE_9_12_3";
            break;
        case WIRE_6_9_12:
            typeStr = "WIRE_6_9_12";
            break;
        case WIRE_9_12_DOUBLE:
            typeStr = "WIRE_9_12_DOUBLE";
            break;
        case WIRE_12_3_DOUBLE:
            typeStr = "WIRE_12_3_DOUBLE";
            break;
        default:
            typeStr = "UNKNOWN";
            //might want to signal an error here
            break;
        }

        if (tileStates[i].leftNode != NULL)
            l = tileStates[i].leftNode->id;

        if (tileStates[i].rightNode != NULL)
            r = tileStates[i].rightNode->id;

        if (tileStates[i].topNode != NULL)
            t = tileStates[i].topNode->id;

        if (tileStates[i].bottomNode != NULL)
            b = tileStates[i].bottomNode->id;

        sprintf(bigBuff, "\r\n\t\tl: %d\r\n\t\tr: %d\r\n\t\tt: %d\r\n\t\tb: %d\r\n",
                l, r, t, b);


        sprintf(buffer, "%s%s%s", typeStr, (tileStates[i].orientation == -1) ? " (flipped)" : "", bigBuff);
        uPrint(buffer);

        /* let the TX buffer empty a bit */
        __delay_cycles(400000);
    }
}

/* Checks for which probes are present on the board, and runs the circuit graph traversal
 * on each one, starting from the probe in question. Then prints results */
void printProbes() {
    uPrint("\r\n");

    if (currProbeATile && currProbeANode) {
        uPrint("\tProbe 1: ");
        unvisitAllNodes(tileStates);

        switch (getNodeValue(currProbeANode, currProbeATile)) {
        case ONE:
            uPrint("1\r\n");
            break;
        case ZERO:
            uPrint("0\r\n");
            break;
        case INDETERMINATE:
            uPrint("Indeterminate -- poorly formed circuit\r\n");
            break;
        default:
            break;
        }

#ifdef _DEBUG_ON
       char buf[30];
       sprintf(buf, "\t\tProbe Left Node: %d\r\n", currProbeANode->id);
       uPrint(buf);
#endif
    }

    if (currProbeBTile && currProbeBNode) {
        uPrint("\tProbe 2: ");
        unvisitAllNodes(tileStates);

        switch (getNodeValue(currProbeBNode, currProbeBTile)) {
        case ONE:
            uPrint("1\r\n");
            break;
        case ZERO:
            uPrint("0\r\n");
            break;
        case INDETERMINATE:
            uPrint("Indeterminate -- poorly formed circuit\r\n");
            break;
        default:
            break;
        }

#ifdef _DEBUG_ON
       char buf[30];
       sprintf(buf, "\t\tProbe Left Node: %d\r\n", currProbeBNode->id);
       uPrint(buf);
#endif
    }

    if (currProbeCTile && currProbeCNode) {
        uPrint("\tProbe 3: ");
        unvisitAllNodes(tileStates);

        switch (getNodeValue(currProbeANode, currProbeCTile)) {
        case ONE:
            uPrint("1\r\n");
            break;
        case ZERO:
            uPrint("0\r\n");
            break;
        case INDETERMINATE:
            uPrint("Indeterminate -- poorly formed circuit\r\n");
            break;
        default:
            break;
        }

#ifdef _DEBUG_ON
       char buf[30];
       sprintf(buf, "\t\tProbe Left Node: %d\r\n", currProbeCNode->id);
       uPrint(buf);
#endif
    }

    if (currProbeDTile && currProbeDNode) {
        uPrint("\tProbe 4: ");
        unvisitAllNodes(tileStates);

        switch (getNodeValue(currProbeDNode, currProbeDTile)) {
        case ONE:
            uPrint("1\r\n");
            break;
        case ZERO:
            uPrint("0\r\n");
            break;
        case INDETERMINATE:
            uPrint("Indeterminate -- poorly formed circuit\r\n");
            break;
        default:
            break;
        }

 #ifdef _DEBUG_ON
        char buf[30];
        sprintf(buf, "\t\tProbe Left Node: %d\r\n", currProbeDNode->id);
        uPrint(buf);
#endif
    }
}

/* Sets the source associated with the passed char, or prints error if none */
void setSource(char source) {
#ifdef _DEBUG_ON
    char tempBuf[30];
    sprintf(tempBuf, "\r\nSource to set: %c", source);
    uPrint(tempBuf);
#endif

    uPrint("\r\n");

    switch (source) {
    case 'a':
    case 'A':
        uPrint("\tSource A set.\r\n");
        currSourceA = ONE;
        break;

    case 'b':
    case 'B':
        uPrint("\tSource B set.\r\n");
        currSourceB = ONE;
        break;

    case 'c':
    case 'C':
        uPrint("\tSource C set.\r\n");
        currSourceB = ONE;
        break;

    case 'd':
    case 'D':
        uPrint("\tSource D set.\r\n");
        currSourceB = ONE;
        break;

    default:
        uPrint("\tNo such source to set.\r\n");
        break;
    }
}

/* Clears the source associated with the passed char, or prints error if none */
void clearSource(char source) {
    uPrint("\r\n");

    switch (source) {
    case 'a':
    case 'A':
        uPrint("\tSource A cleared.\r\n");
        currSourceA = ZERO;
        break;

    case 'b':
    case 'B':
        uPrint("\tSource B cleared.\r\n");
        currSourceB = ZERO;
        break;

    case 'c':
    case 'C':
        uPrint("\tSource C cleared.\r\n");
        currSourceB = ZERO;
        break;

    case 'd':
    case 'D':
        uPrint("\tSource D cleared.\r\n");
        currSourceB = ZERO;
        break;

    default:
        uPrint("\tNo such source to clear.\r\n");
        break;
    }
}

/* Moves char pointer to next token (after whitespace) in string, returning tht location (or null) */
char *nextToken(char *tok) {
    while(*tok && *tok != ' ' && *tok != '\n' && *tok != '\r')
        tok++;

    while (*tok) {
        if (*tok == ' ' || *tok == '\n' || *tok == '\r')
            tok++;
        else
            break;
    }

    return tok;
}

/* Copies the message into the ring buffer, potentially overwriting data that has not
 * yet been TXed if message is particularly long or buffer size too small. Message should be
 * null-terminated */
void uPrint(char *message) {
    int messageLen = strlen(message);
    unsigned int i;

    for (i = 0; i < messageLen; i++) {
        printBuff[ringNdx] = message[i];

        ringNdx++;

        if (ringNdx == PRINT_BUFFER_SIZE)
            ringNdx = 0;
    }

    if (numPendingTX == 0) {
        numPendingTX += messageLen;
        UCA0IFG |= UCTXIFG;             //Trigger TX interrupt if send isn't already happening
    }
    else
        numPendingTX += messageLen;
}

/* Adds a single char to the TX ring buffer */
void uPrintChar(char c) {
    printBuff[ringNdx] = c;

    ringNdx++;
    if (ringNdx == PRINT_BUFFER_SIZE)
        ringNdx = 0;

    if (numPendingTX == 0) {
        numPendingTX++;
        UCA0IFG |= UCTXIFG;             //Trigger TX interrupt if send isn't already happening
    }
    else
        numPendingTX++;
}

/* Prints the passed value, in hex. Meant for debugging ADC */
void printADC(uint16_t value) {
    char buffer[4];
    sprintf(buffer, "%x", value);

    uPrint(buffer);
}

void printCmds() {
    uPrint("\r\nCommands:");
    uPrint("\r\n\tprintTiles:\t\tList all tiles and their known states");
    uPrint("\r\n\tset <source-letter>:\tSet the given source to HIGH (1)");
    uPrint("\r\n\tclear <source-letter>:\tClear the given source to LOW (0)");
    uPrint("\r\n\trun:\t\t\tPrint the values of all the probes on the board");
    uPrint("\r\n");
}

/* More of a framework for a potential error-reporting system */
void reportError(int errorCode) {

    switch (errorCode) {

        case BAD_CMD:
            uPrint("\r\nERROR: INPUT ERROR (preceeding input was lost) ");

            break;

        default:
            break;

    }

    uPrint("\r\n>: ");
}

/* One-time configuration for I/O and various features */
void init() {
    WDTCTL = WDTPW | WDTHOLD;                   // Stop watchdog timer
    PM5CTL0 &= ~LOCKLPM5;                       // Disable the GPIO power-on default high-impedance mode
                                                // to activate previously configured port settings

    P1DIR |= LED0 | LED1;                       //Set LEDs as output
    P4DIR |= TILE_CTRL;                         //Set Tile select pins as outputs
    P2DIR |= MAG_CTRL;                          //Set Mag select pins as outputs
    P3DIR |= MODULE_CTRL;                       //Set Module select pins as outputs

    initADC();
    initUSART();
    initTileState();
    initNodes();

    unvisitAllNodes(tileStates);
    selectBoardTile(0);                         //Initialize board tile selection to 0 to start w/ known state
}

/*
 * Initializes ADC1 with input P1.5
 */
void initADC() {

    P1SEL1 |= BIT5 | BIT4;                          // Configure P1.5 & P1.4 for ADC
    P1SEL0 |= BIT5 | BIT4;

    P3SEL1 |= BIT3;                                 // Configure P3.3 for ADC
    P3SEL0 |= BIT3;

    // Configure ADC12
    ADC12CTL0 = ADC12SHT0_2 | ADC12ON;              // Sampling time, S&H=16, ADC12 on
    ADC12CTL1 = ADC12SHP;            // Use sampling timer
    ADC12CTL2 |= ADC12RES_2;                        // 12-bit conversion results


    ADC12MCTL0 |= ADC12INCH_5;                      // A5 ADC input select; Vref=AVCC

    ADC12IER0 |= ADC12IE0;                          // Enable ADC conv complete interrupt
}

/*
 * Initializes USART 01
 * NOTE: This function has not been tested yet!
 */
void initUSART() {

    P2SEL0 &= ~(BIT0 | BIT1);
    P2SEL1 |= BIT0 | BIT1;                  // USCI_A0 UART operation

    // Startup clock system with max DCO setting ~8MHz
    CSCTL0_H = CSKEY_H;                     // Unlock CS registers
    CSCTL1 = DCOFSEL_3 | DCORSEL;           // Set DCO to 8MHz
    CSCTL2 = SELA__VLOCLK | SELS__DCOCLK | SELM__DCOCLK;
    CSCTL3 = DIVA__1 | DIVS__1 | DIVM__1;   // Set all dividers
    CSCTL0_H = 0;                           // Lock CS registers

    // Configure USCI_A0 for UART mode
    UCA0CTLW0 = UCSWRST;                    // Put eUSCI in reset
    UCA0CTLW0 |= UCSSEL__SMCLK;             // CLK = SMCLK
    UCA0BRW = 52;                           // 8000000/16/9600
    UCA0MCTLW |= UCOS16 | UCBRF_1 | 0x4900;
    UCA0CTLW0 &= ~UCSWRST;                  // Initialize eUSCI
    UCA0IE |= UCRXIE;                       // Enable USCI_A0 RX interrupt

    UCA0IE |= UCTXIE;                       // Enable USCI_A0 TX interrupt
}

/* Initializes the known states of each tile to U (no magnet present) */
void initTileState() {
    unsigned int i;
    for (i = 0; i < NUM_TILES; i++) {
        tileStates[i].mag0 = U;
        tileStates[i].mag1 = U;
        tileStates[i].mag2 = U;
        tileStates[i].type = EMPTY;
        tileStates[i].orientation = 1;

        tileStates[i].leftNode = 0;
        tileStates[i].rightNode = 0;
        tileStates[i].topNode = 0;
        tileStates[i].bottomNode = 0;
    }
}

/* Blocking function that initializes and waits out an ADC read and returns the magnet
 * encoding for the currently mux-selected hall-effect sensor (selected with selectBoardTile() and selectMag()
 * in tiles.c). Performs multiple reads and averages them before interpreting the encoding value */
magcode readTileMag() {
    magcode returnCode = U;
    uint16_t adcAvg, i = 0;

    /* Average reads together */
    for (i = 0, adcAvg = 0; i < ADC_AVG_COUNT; i++) {
        adcRead = 0;
        ADC12CTL0 |= ADC12ENC | ADC12SC;        // Start sampling/conversion

        while(adcRead == 0)
           ;

        adcAvg = (i == 0) ? lastReadADCValue : (adcAvg + lastReadADCValue);
    }

    adcAvg /= i;

#ifdef _ADC_DUMP
    uPrint("ADC VAL: ");
    printADC(adcAvg);
    uPrint("\r\n");
    __delay_cycles(200000);
#endif

    if (adcAvg < U_MIN) {
        if (adcAvg < S2_MIN)
            returnCode = S1;
        else
            returnCode = S2;
    }
    else if (adcAvg > U_MAX) {
        if (adcAvg > N2_MAX)
            returnCode = N1;
        else
            returnCode = N2;
    }

    adcRead = 0;
    return returnCode;
}

/*
 * ADC INTERRUPT VECTOR
 */
#if defined(__TI_COMPILER_VERSION__) || defined(__IAR_SYSTEMS_ICC__)
#pragma vector = ADC12_B_VECTOR
__interrupt void ADC12_ISR(void)
#elif defined(__GNUC__)
void __attribute__ ((interrupt(ADC12_B_VECTOR))) ADC12_ISR (void)
#else
#error Compiler not supported!
#endif
{
    switch(__even_in_range(ADC12IV, ADC12IV__ADC12RDYIFG))
    {
        case ADC12IV__NONE:        break;   // Vector  0:  No interrupt
        case ADC12IV__ADC12OVIFG:  break;   // Vector  2:  ADC12MEMx Overflow
        case ADC12IV__ADC12TOVIFG: break;   // Vector  4:  Conversion time overflow
        case ADC12IV__ADC12HIIFG:  break;   // Vector  6:  ADC12BHI
        case ADC12IV__ADC12LOIFG:  break;   // Vector  8:  ADC12BLO
        case ADC12IV__ADC12INIFG:  break;   // Vector 10:  ADC12BIN

        case ADC12IV__ADC12IFG0:            // Vector 12:  ADC12MEM0 Interrupt
            lastReadADCValue = ADC12MEM0;
            adcRead = 1;

            // Exit from LPM0 and continue executing main
            __bic_SR_register_on_exit(LPM0_bits);

            break;

        case ADC12IV__ADC12IFG3:   break;   // Vector 18:  ADC12MEM3
        case ADC12IV__ADC12IFG4:   break;   // Vector 20:  ADC12MEM4
        case ADC12IV__ADC12IFG5:   break;   // Vector 22:  ADC12MEM5
        case ADC12IV__ADC12IFG6:   break;   // Vector 24:  ADC12MEM6
        case ADC12IV__ADC12IFG7:   break;   // Vector 26:  ADC12MEM7
        case ADC12IV__ADC12IFG8:   break;   // Vector 28:  ADC12MEM8
        case ADC12IV__ADC12IFG9:   break;   // Vector 30:  ADC12MEM9
        case ADC12IV__ADC12IFG10:  break;   // Vector 32:  ADC12MEM10
        case ADC12IV__ADC12IFG11:  break;   // Vector 34:  ADC12MEM11
        case ADC12IV__ADC12IFG12:  break;   // Vector 36:  ADC12MEM12
        case ADC12IV__ADC12IFG13:  break;   // Vector 38:  ADC12MEM13
        case ADC12IV__ADC12IFG14:  break;   // Vector 40:  ADC12MEM14
        case ADC12IV__ADC12IFG15:  break;   // Vector 42:  ADC12MEM15
        case ADC12IV__ADC12IFG16:  break;   // Vector 44:  ADC12MEM16
        case ADC12IV__ADC12IFG17:  break;   // Vector 46:  ADC12MEM17
        case ADC12IV__ADC12IFG18:  break;   // Vector 48:  ADC12MEM18
        case ADC12IV__ADC12IFG19:  break;   // Vector 50:  ADC12MEM19
        case ADC12IV__ADC12IFG20:  break;   // Vector 52:  ADC12MEM20
        case ADC12IV__ADC12IFG21:  break;   // Vector 54:  ADC12MEM21
        case ADC12IV__ADC12IFG22:  break;   // Vector 56:  ADC12MEM22
        case ADC12IV__ADC12IFG23:  break;   // Vector 58:  ADC12MEM23
        case ADC12IV__ADC12IFG24:  break;   // Vector 60:  ADC12MEM24
        case ADC12IV__ADC12IFG25:  break;   // Vector 62:  ADC12MEM25
        case ADC12IV__ADC12IFG26:  break;   // Vector 64:  ADC12MEM26
        case ADC12IV__ADC12IFG27:  break;   // Vector 66:  ADC12MEM27
        case ADC12IV__ADC12IFG28:  break;   // Vector 68:  ADC12MEM28
        case ADC12IV__ADC12IFG29:  break;   // Vector 70:  ADC12MEM29
        case ADC12IV__ADC12IFG30:  break;   // Vector 72:  ADC12MEM30
        case ADC12IV__ADC12IFG31:  break;   // Vector 74:  ADC12MEM31
        case ADC12IV__ADC12RDYIFG: break;   // Vector 76:  ADC12RDY
        default: break;
    }
}
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

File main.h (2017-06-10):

/* MSP430 Logic Tiles Project - main.h
 *
 * Most of the implementation-specific defines for the project.
 *
 * Authors: Tristan Lennertz & Andrew Wheeler
 */

#ifndef MAIN_H
#define MAIN_H

#include <stdio.h>
#include <stdint.h>
#include "tiles.h"

/* Defines for the number and layout of modules. Must be in a rectangular layout
 * for the modules, but works with any particular dimmension of such. */
#define NUM_TILES (24)       //8 * number of modules comprising the board

#define MODULE_COLUMNS (1)  //The number of modules making up the board's width
#define MODULE_ROWS (3)     //The number of modules making up the board's height

#define TILE_WIDTH (4)      //4 * MODULE_COLUMNS
#define TILE_HEIGHT (6)     //2 * MODULE_ROWS

/* The maximum possible nodes that could exist in a graph produced by this board.
 * Alternatively, just calculate it and put that as a straight define. Can also
 * set this value to something lower and malloc if the number of needed nodes exceeds
 * what's pre-allocated. We have opted to avoid malloc altogether in this implementation */
#define MAX_NODES ((10 * MODULE_COLUMNS * MODULE_ROWS) + \
                   (2 * (MODULE_COLUMNS - 1) * MODULE_ROWS) + \
                   (4 * (MODULE_ROWS - 1) * MODULE_COLUMNS))

/* Hall Effect Sensor Value ranges for each magcode. May need to be adjusted for
 * the particular ADC and the application's distance of the magnet from each sensor
 * Note that S2 and N2 correspond to the values closer to the U range, being in
 * the deeper tile holes. N1 and S1 are the shallower tile holes with values
 * that range further from U than N2 and S2 */
#define U_MIN 0x4B0     //Min of the no-magnet-detected range
#define U_MAX 0x52F     //Max of the no-magnet-detected range
#define S2_MIN 0x400    //Min of the "weak" south magnet range.
#define N2_MAX 0x5DF    //Max of the "weak" north magnet range

/* The various states of the main loop state machine */
typedef enum{IDLE_POLL, CMD_PARSE, UPDATE_CKT} state;

/* Internal representation of digital values */
typedef enum {ZERO, ONE, INDETERMINATE, UNVISITED} digiVal;

/* Specific Pins used for ADC, Tile Muxing, and Magnet Muxing */
#define ADC1_PIN 0x06 //Port 1, Pin 5 (A5)

#define TILE_CTRL 0b00001110    //Pins 1-3 on Port 4
#define TILE_SEL0 (BIT1)
#define TILE_SEL1 (BIT2)
#define TILE_SEL2 (BIT3)

#define MAG_CTRL 0b01100000     //Pins 5 & 6 on Port 2
#define MAG_SEL0 (BIT5)
#define MAG_SEL1 (BIT6)

#define MODULE_CTRL 0b00000111  //Pins 0 - 2 on Port 3
#define MODULE_SEL0 (BIT0);
#define MODULE_SEL1 (BIT1);
#define MODULE_SEL2 (BIT2);

/* Number of measurements that is made with the ADC and averaged for a single
 * magnet read. */
#define ADC_AVG_COUNT 8

/* Error Codes */
#define BAD_CMD 1

/* Current Values of the Source Tiles (set by commands) */
extern digiVal currSourceA;
extern digiVal currSourceB;
extern digiVal currSourceC;
extern digiVal currSourceD;

struct Node;

/* Current Nodes and Tiles of Probe Blocks */
extern struct Node *currProbeANode;
extern struct Node *currProbeBNode;
extern struct Node *currProbeCNode;
extern struct Node *currProbeDNode;

extern TileState *currProbeATile;
extern TileState *currProbeBTile;
extern TileState *currProbeCTile;
extern TileState *currProbeDTile;

/* function declarations */
void init();

void initADC();
void initUSART();
void initTileState();

state idlePoll();
state cmdParse();

void uPrint(char * message);
void printCmds();
void printADC(uint16_t value);
void printTiles();
void printProbes();
void setSource(char source);
void clearSource(char source);
char *nextToken(char *tok);

magcode readTileMag();

/* Quick and dirty defines from our specific applications */
//Tile Bit Masks
#define TILE_0 0b00000000
#define TILE_1 0b00000010
#define TILE_2 0b00000100
#define TILE_3 0b00000110
#define TILE_4 0b00001000
#define TILE_5 0b00001010
#define TILE_6 0b00001100
#define TILE_7 0b00001110

//Magnet Bit Masks
#define MAG_0 0b00100000
#define MAG_1 0b01000000
#define MAG_2 0b01100000

//PIN DEFINITIONS
#define LED0 0x01
#define LED1 0x02
#define ADC_5 0x06
#endif

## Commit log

2017-05-14 First Push
    Blinking LED
2017-05-15 Error?
    Where is it?
    [main.c]
2017-05-15 End of Day 5/14
    Can Cycle through all magnets and tiles and get a good read.
2017-05-20 UART Enabled
    Now we got UART!
2017-05-20 Polling Tiles Framework
    Added the flow of polling all the tiles. Still needs specific
    implementations on pins and magnet read value ranges.
2017-05-29 ERRMAGERRRHD. GRERPHS.
    Added graph.c/h, with backbone for building circuit graph. Also updated
    TileState structure to have pointers to potential nodes on a tile's
    bottom, top, right, and left sides.
2017-05-29 Using your Nodal!
    Implemented methods of adding nodes to our graph.c. When a new tile is
    placed on the board, nodes are added to each of the end points of a tile
    and are used to connect various tiles together. Each node connect two
    tiles at either a vertial or horizontal connection.
2017-06-01 Fixed N1 S2 Defines, Cleaned up Main.c
    [main.c, main.h]
2017-06-01 Read ADC
    Added function to print read ADC values
2017-06-02 Graph Building
    Should be correct (if not slightly confusing)
    [main.c, main.h]
2017-06-02 Finished Up The Graph Recursion
    And also fixed a few graph building things. Hopefully.
    [main.c, main.h]
2017-06-04 Added TX Interrupt functionality with a ring buffer
2017-06-06 Most things fixed. New tiles might do it
    [main.c, main.h, tiles.c]
2017-06-10 Project Files Added
    [Eagle.sch, Single_Module_Mount_Bottom.stl, Single_Module_Mount_Top.stl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]
